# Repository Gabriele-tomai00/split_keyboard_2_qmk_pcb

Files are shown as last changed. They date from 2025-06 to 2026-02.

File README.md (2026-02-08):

# SPLIT KEYBOARD (my second version)

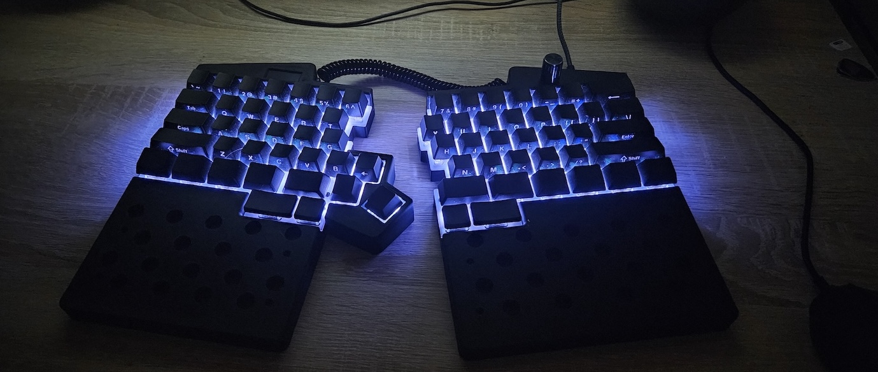
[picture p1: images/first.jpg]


<!-- ## ⚠️ Report In Progress ⚠️ -->
This project details the design and construction of my first custom split keyboard. The build features a custom PCB, hand-soldered components, and a 3D-printed case, all powered by the Raspberry Pi Pico and QMK firmware.

**Key Features:**
- **Microcontroller**: Raspberry Pi Pico (RP2040)
- **Firmware**: QMK with Vial GUI support
- **Switches**: Hot-swappable MX switches
- **Displays**: OLED status screens
- **Input**: Rotary encoders
- **Interconnect**: RJ11 cabling for safe hot-plugging

The layout is a traditional row-staggered design (non-ortholinear) with ergonomic enhancements:
- **Inner Macro Keys**: 3 extra keys on the inner side of the right half.
- **Thumb Cluster**: 2 low-profile keys under each spacebar, primarily used as layer modifiers.

*Acknowledgments: Special thanks to the QMK and Vial communities, and the authors of the Sofle Pico keyboard, whose work provided invaluable inspiration and knowledge.*

## Repository Structure
- `/3d_images`: 3D design files (STL) created with Autodesk Fusion 360
- `/images`: Photographic documentation of the keyboard assembly and final build.
- `/kicad`: Electrical schematics and PCB layout designs developed in KiCad, ready for fabrication.
- `/vial-qmk`: Source code for the QMK-based firmware with Vial GUI support.
- `/vial_config.vil`: Vial configuration file (you can upload this file to Vial to configure the keyboard).
- `/perimeter_right.dxf` and `/perimeter_left.dxf`: DXF files for the right and left half PCB perimeter (used to cut the PCB).

## Components List
- Custom PCBs (Left & Right)
- 2x Raspberry Pi Pico
- 1N4148 Diodes
- Kailh Hot-swap Sockets
- SK6812MINI-E SMD LEDs
- EC11 Rotary Encoders
- 0.91" I2C OLED Displays
- RJ11 Jacks (6P6C or similar)
- Brass Standoffs (M2)

## Features & Implementation

### Layout & Ergonomics
The keyboard deviates slightly from a standard 60% ANSI layout to accommodate split ergonomics. It combines standard MX switches with low-profile switches for the thumb cluster to reduce strain. The extra macro keys on the left half provide quick access to custom functions.

### Software (QMK & Vial)
The keyboard runs on QMK firmware and is fully compatible with Vial. This allows for real-time configuration via a graphical interface without re-flashing. Users can program:
- **Layers**: Toggle between different keymaps (e.g., QWERTY, navigation, numpad).
- **Macros**: Automate complex key sequences.
- **Tap Dance**: Assign different actions to a key based on how many times it is tapped.

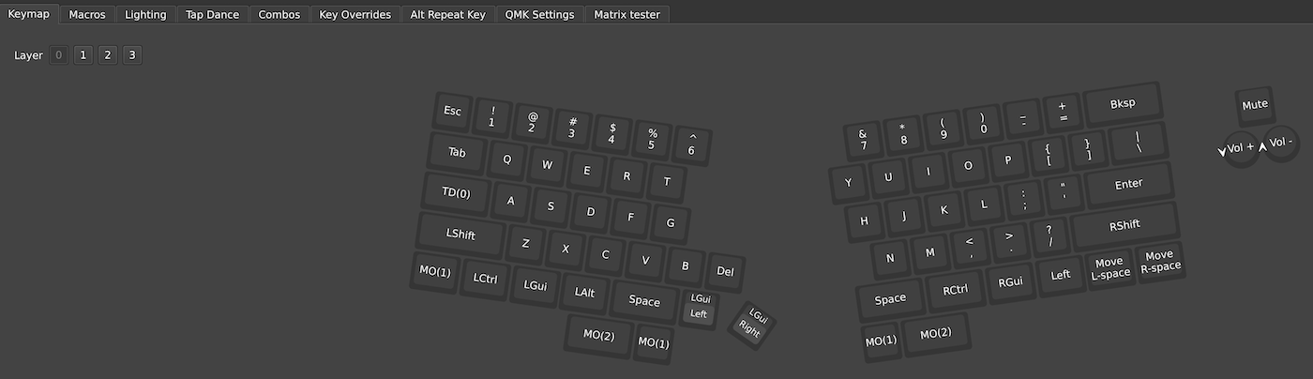
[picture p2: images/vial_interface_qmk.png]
Vial Interface


### Rotary Encoders (EC11)
The keyboard utilizes EC11 rotary encoders. In the QMK ecosystem, encoders provide a fluid input method distinct from binary key presses. They are ideal for continuous values like volume control, page scrolling, or history navigation.

### OLED Displays
Each half is equipped with an OLED display connected via the I2C protocol.

OLED Display

### RGB Backlighting (SK6812MINI-E)
The PCB features per-key RGB backlighting using SK6812MINI-E LEDs.
- **Technology**: These addressable "reverse-mount" LEDs sit within PCB cutouts, shining upwards through the switch housing.
- **Effects**: Powered by QMK's RGB Matrix system, the keyboard supports vast lighting animations, reactive typing effects, and layer-specific color coding (e.g., turning the keyboard red when on the "Function" layer).

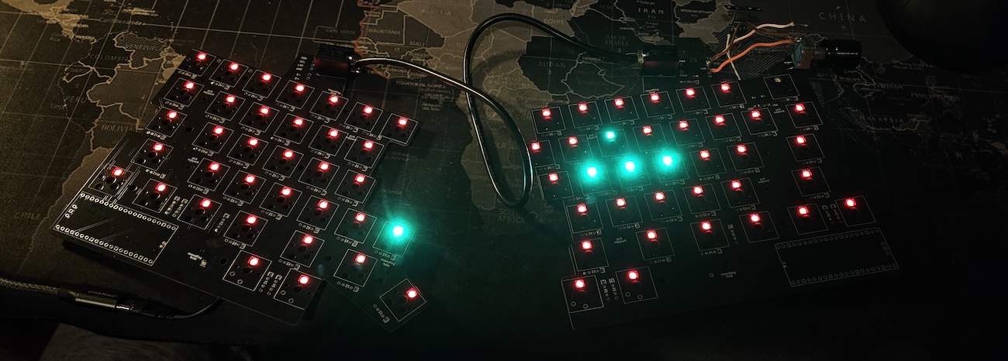
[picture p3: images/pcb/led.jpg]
PCB LED

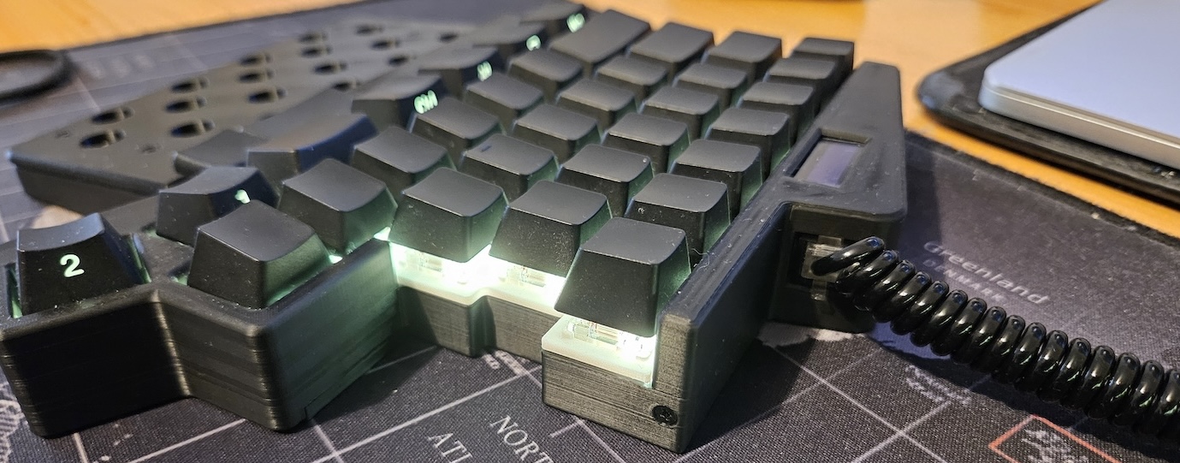
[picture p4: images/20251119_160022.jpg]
Backlighting


## Hardware Details

### Microcontroller: Raspberry Pi Pico (RP2040)
I selected the Raspberry Pi Pico for this build due to its generous GPIO count compared to the Pro Micro. With 26 usable GPIO pins, the RP2040 handles the matrix, encoders, OLEDs, and RGB data lines directly, simplifying the PCB design.

### Split Connection: UART via RJ11
Communication between the two halves uses Full Duplex UART over an RJ11 cable (inspired by the Ultimate Hacking Keyboard).
- **Why RJ11?**: Unlike the common TRRS (Aux) cables used in many split keyboards, RJ11 connectors do not short pins momentarily during insertion or removal. This design choice eliminates the risk of shorting VCC to GND while the keyboard is powered.

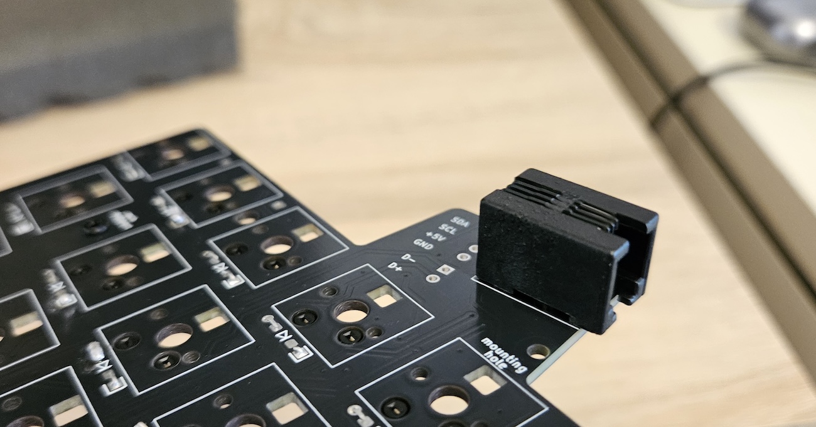
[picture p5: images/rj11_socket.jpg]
RJ11 Socket


I constructed a custom cable using 4-pin RJ11 connectors (6P4C) attached to a 4-core wire. It is crucial to ensure the connectors support at least 4 pins, avoiding the common 2-pin variants typically used for telephone lines in Italy.

### USB Type-C Connectivity
Each keyboard half features a dedicated USB Type-C port for computer connectivity. I chose this standard for its versatility and widespread adoption. The port is distinct from the inter-half connection to prevent accidental mismatches. Either half can be connected to the host computer.
I referenced the Raspberry Pi Pico datasheet to correctly wire the external USB-C breakout board to the microcontroller, ensuring the Pico detects the external connection as its primary USB interface.

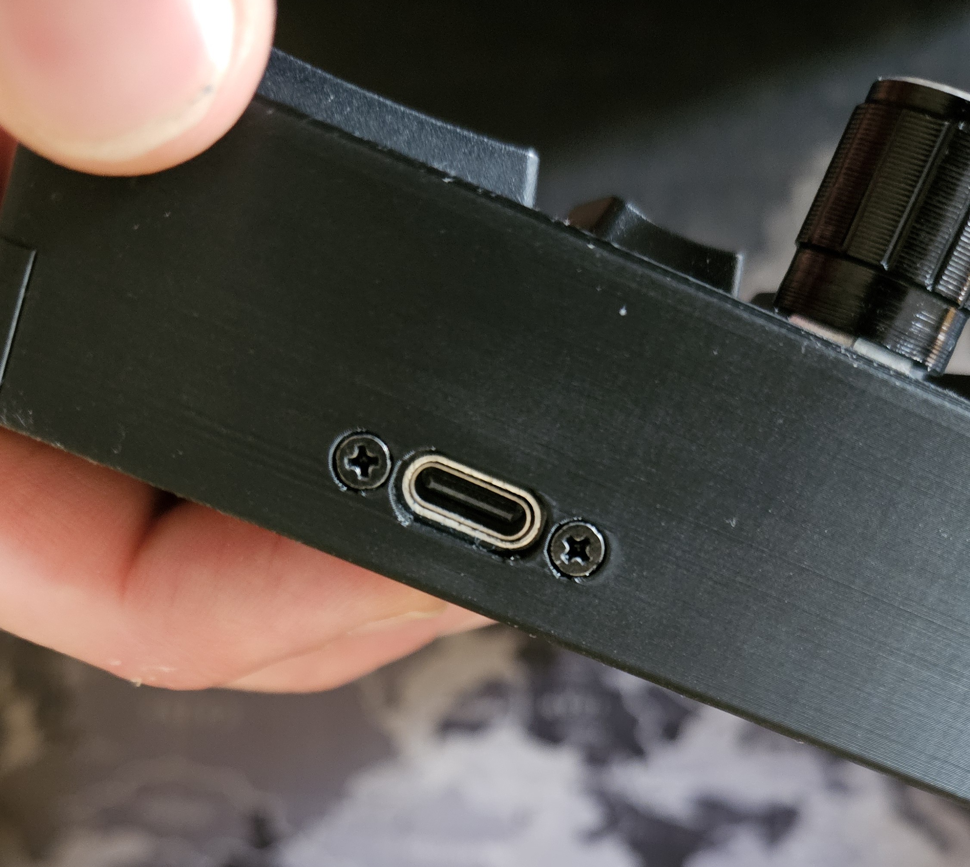
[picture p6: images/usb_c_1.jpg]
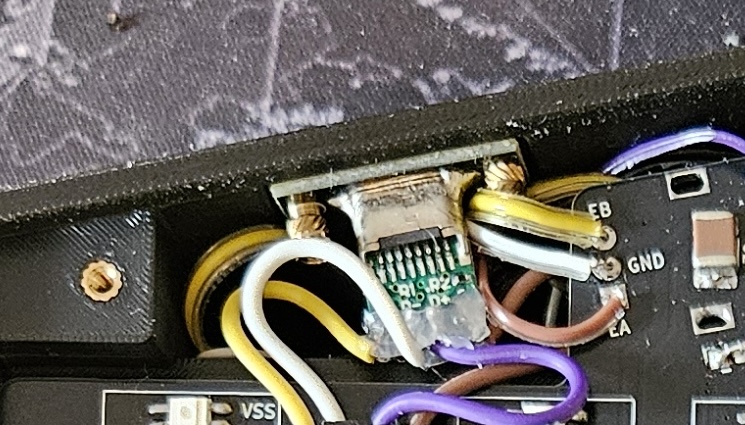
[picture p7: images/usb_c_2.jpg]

### Key Matrix Wiring
QMK supports a key matrix configuration where each key is identified by a unique row-column combination, with diodes preventing ghosting (unwanted column activation).
The PCB and QMK firmware are configured as follows:
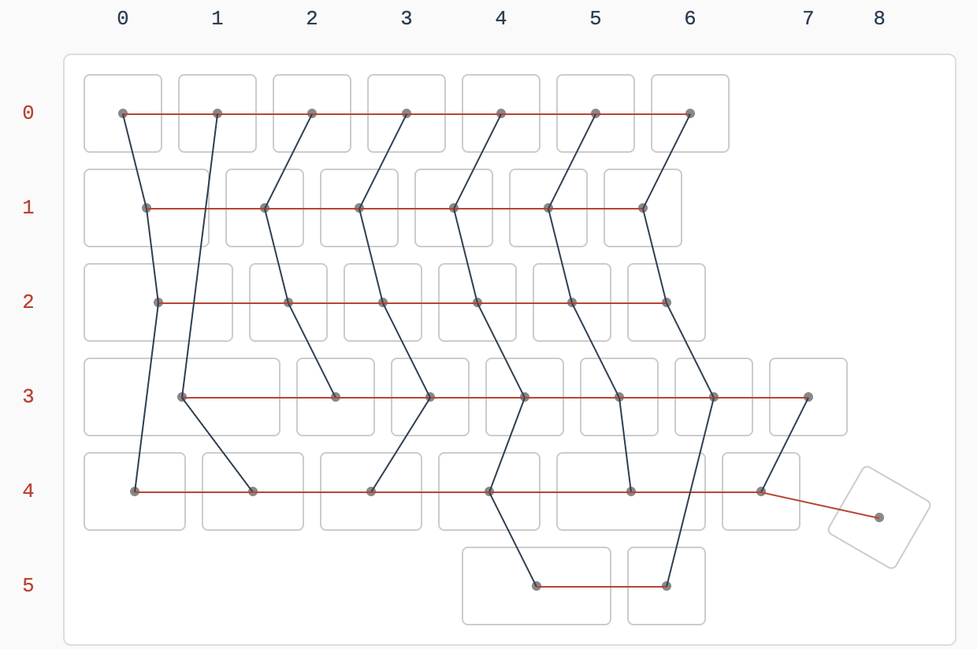
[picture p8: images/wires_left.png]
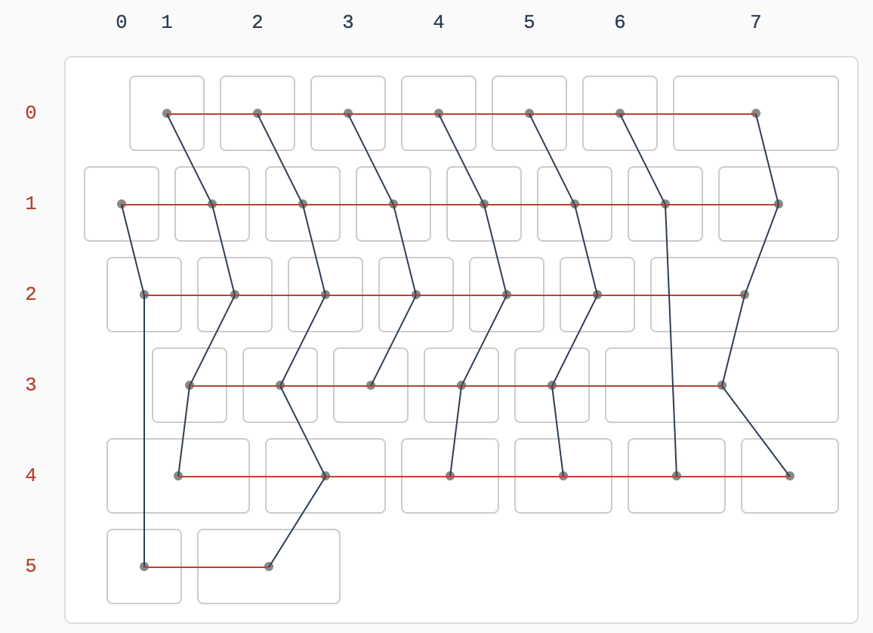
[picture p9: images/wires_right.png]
 

## 3D-Printed Case Design
I designed with Autodesk Fusion 360 and printed a custom enclosure using PLA. The chassis is modular, divided into multiple parts to:
- Allow for easy replacement of individual components without re-printing the entire case.
- Reduce print time per part (avoiding >20h single prints).

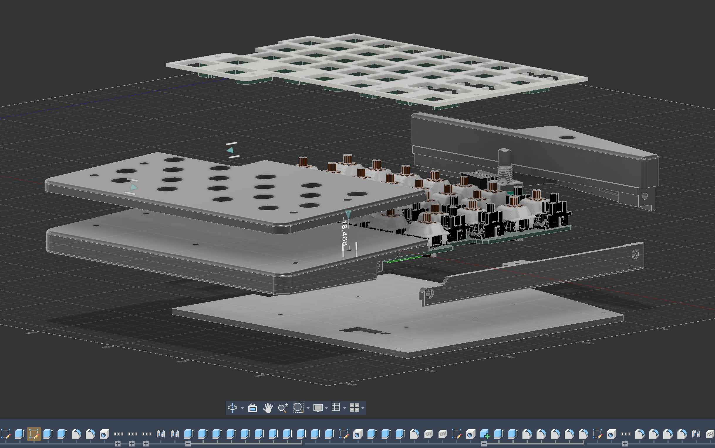
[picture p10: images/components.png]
Components


### 3D Printing Process
The enclosure components were manufactured using a Bambu Lab P1P 3D printer. While the design is compatible with standard printing profiles, a 0.2mm nozzle was utilized to achieve superior surface finish and precise detail resolution.
PLA (Polylactic Acid) was selected as the filament material due to its optimal balance of cost-effectiveness, printability, and mechanical durability suitable for this application.

### Assembly
The case uses threaded brass inserts (M2) for a robust and aesthetically pleasing assembly.
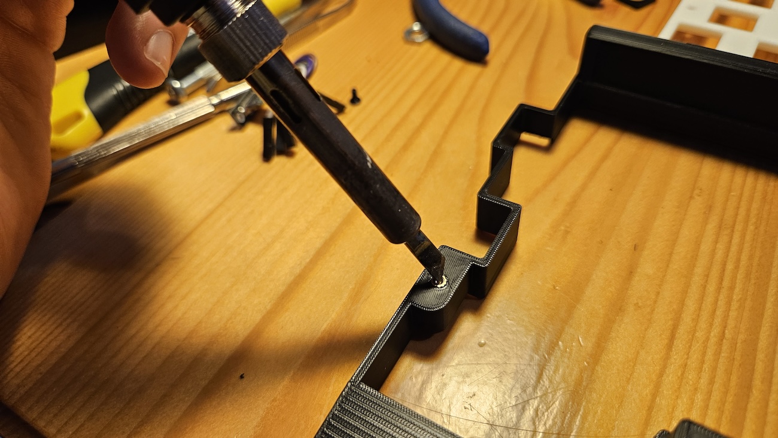
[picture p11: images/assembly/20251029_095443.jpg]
Case Assembly

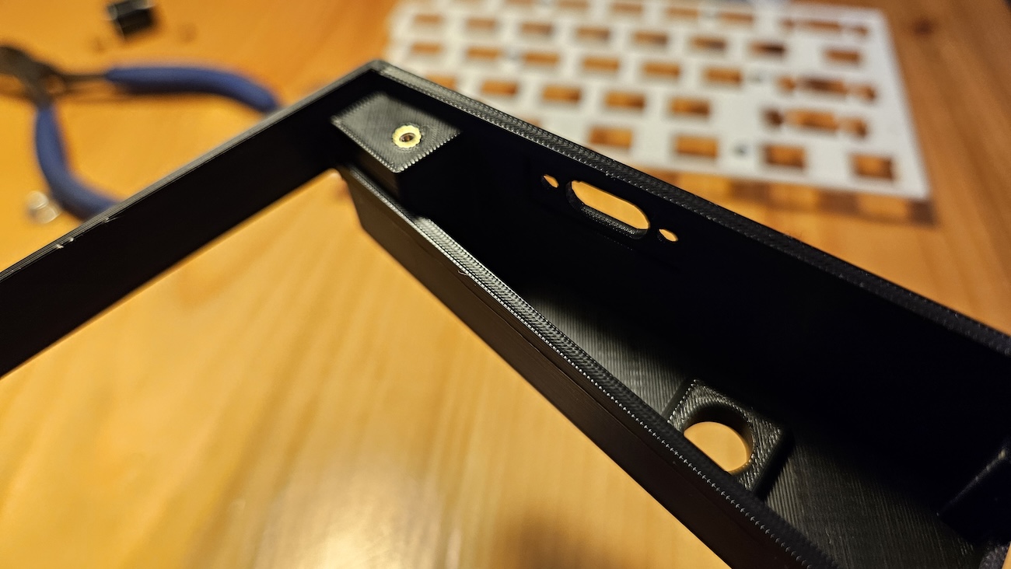
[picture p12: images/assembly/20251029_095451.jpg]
Case Assembly

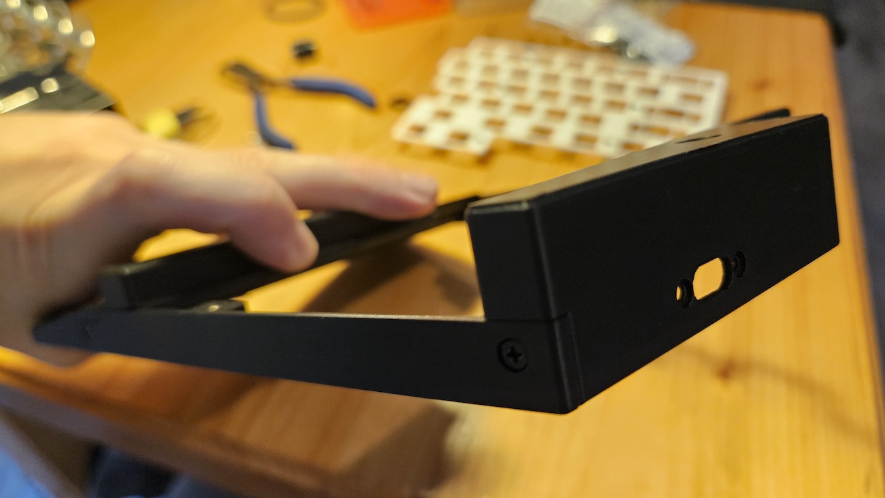
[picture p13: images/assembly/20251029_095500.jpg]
Case Assembly


## Component Assembly & Soldering
All PCB components were hand-soldered, which included:
- **Raspberry Pi Pico**: Soldering all GPIO pins plus the two small test pads required for the external USB data lines.
- **Passive Components**: 2 capacitors per PCB.
- **Connectors**: External USB-C breakout (4 pins) and RJ11 jacks (4 pins).
- **Peripherals**: Rotary encoders (5 pins) and OLED display headers (4 pins).

For the matrix:
- **Diodes**: 1N4148 diodes for each key (2 points).
- **Sockets**: Kailh hot-swap sockets (2 points) - switches are not soldered directly.
- **LEDs**: SK6812MINI-E SMD LEDs (4 points per key).

A significant challenge was soldering the small voltage level shifter required for correct LED data signaling. As this was my first experience with soldering—especially with such small SMD components—the results are functional but reflect the learning curve involved.

## Flashing Instructions
1. Set up the **vial-qmk** environment by cloning the repository: [https://github.com/vial-kb/vial-qmk](https://github.com/vial-kb/vial-qmk).
2. Copy the `qmk-vial/new_split_keyboard_gabriele` directory from this project into the `vial-qmk/keyboards/` directory.
3. Flash the firmware using the following commands:

```bash
# Flash Left Side
qmk flash -kb new_split_keyboard_gabriele -km vial -bl uf2-split-left

# Flash Right Side
qmk flash -kb new_split_keyboard_gabriele -km vial -bl uf2-split-right
```

## Conclusions
Additional photographic documentation is available in the `/images` directory.

## References
- [QMK Firmware](https://qmk.fm/)
- [Raspberry Pi Pico Datasheet](https://datasheets.raspberrypi.com/pico/pico-datasheet.pdf)
- [Sofle Pico Split Keyboard](https://www.soflepico.com)
- [Ultimate Hacking Keyboard - blog](https://uhk.io/blog)
- [VIAL](https://blog.4dcu.be/diy/2023/12/03/pi-pico-usb-c.html)
- [Simple USB Type-C Upgrade for the Raspberry Pi Pico](https://blog.4dcu.be/diy/2023/12/03/pi-pico-usb-c.html)

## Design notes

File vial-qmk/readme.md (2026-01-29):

## Steps
1. Move this git repository to keyboards repository of vial-qmk and rename it to "split_keyboard_gabriele"  
2. use the command (qmk compile -kb "name of the keyboard folder" -km "name of the keyboard layout that is vial if you want to use with vial): 
    `qmk clean && qmk compile -kb new_split_keyboard_gabriele -km vial` or directly `qmk clean && qmk flash -kb new_split_keyboard_gabriele -km vial` (you need a Rasberry Pi Pico linked and in flash mode)
3. It's comulasary use usb connection for the left hand. If you want to link the right hand, you need to change the option #define MASTER_LEFT in config.h

`clear && qmk flash -kb new_split_keyboard_gabriele -km vial` 

`clear && qmk clean && qmk flash -kb new_split_keyboard_gabriele -km vial -bl uf2-split-left` 
`clear && qmk clean && qmk flash -kb new_split_keyboard_gabriele -km vial -bl uf2-split-right`

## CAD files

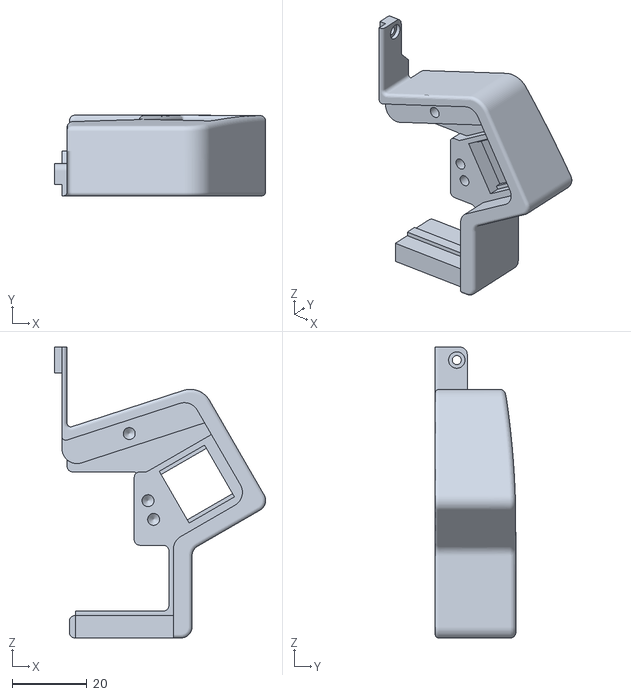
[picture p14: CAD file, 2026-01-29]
3d_models/left_keyboard_part/3-key_keypad.stl
56.5 x 21.6 x 77.9

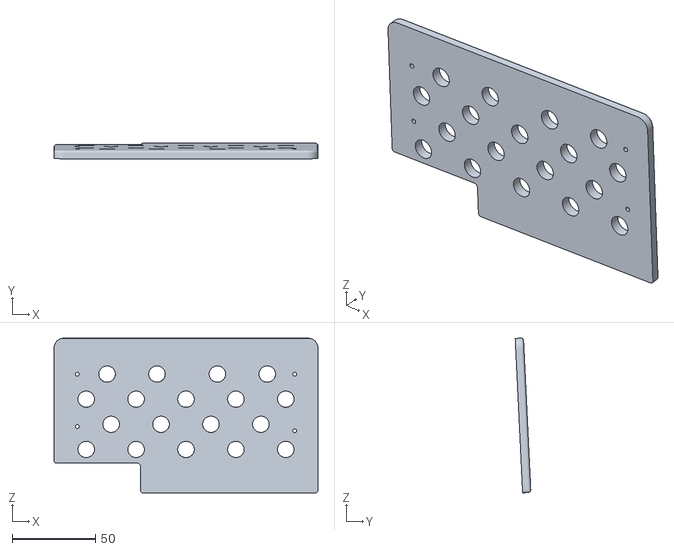
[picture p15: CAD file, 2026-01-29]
3d_models/right_keyboard_part/palm_rest_right.stl
158.7 x 9.38 x 93.1

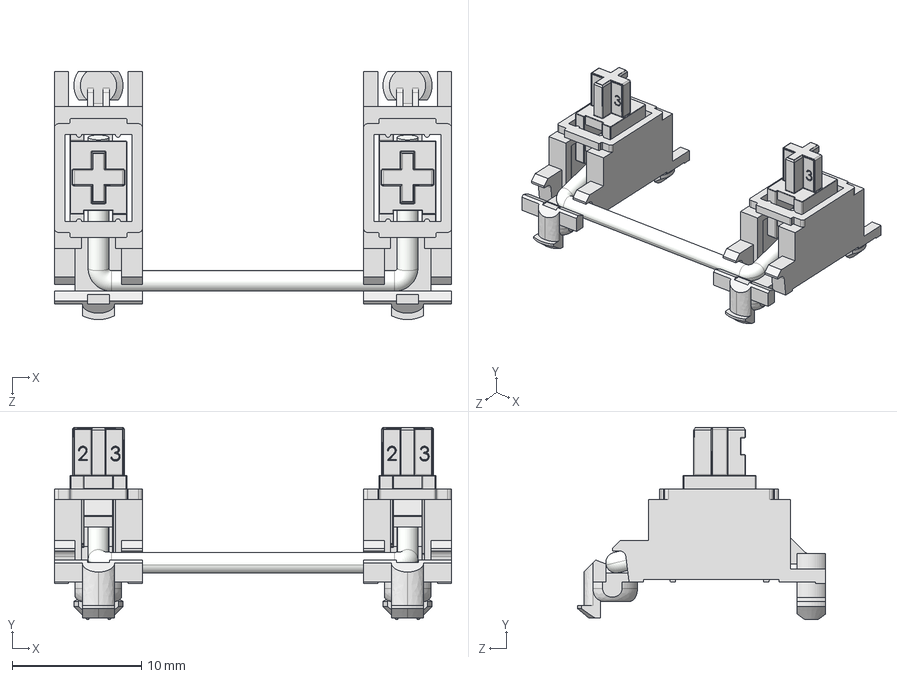
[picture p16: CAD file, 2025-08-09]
kicad/3d_models/Stabilizer.STEP
30.7 x 14.9 x 19.2 mm
mx Stabilizer base 16828 x 2
mx Stabilizer key 16828 x 2
metal stick 16828

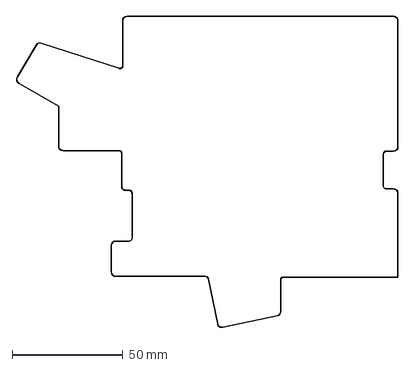
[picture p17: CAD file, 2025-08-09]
kicad/pcb_keyboard_left/perimetro_left.dxf
172.6 x 140.8 mm

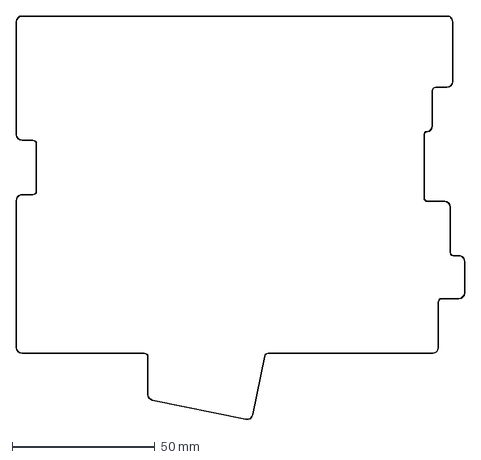
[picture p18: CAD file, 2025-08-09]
kicad/pcb_keyboard_right/perimetro_right.dxf
156.8 x 141.3 mm

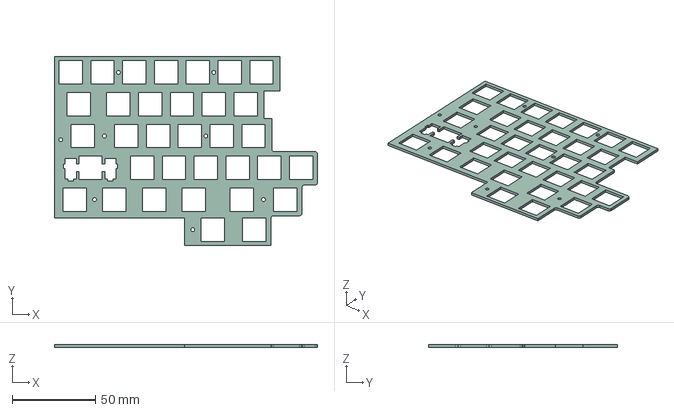
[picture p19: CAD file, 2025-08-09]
kicad/plate/plate_left/plate_left.step
157.6 x 113.2 x 1.60 mm

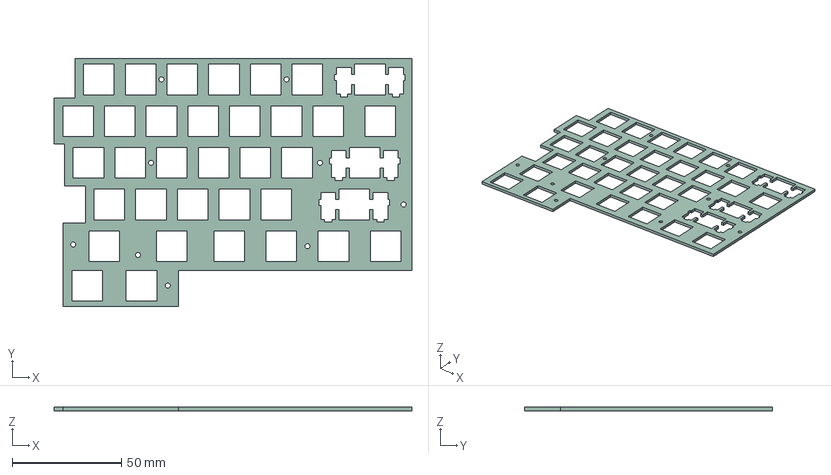
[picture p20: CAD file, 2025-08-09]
kicad/plate/plate_right/plate_right.step
163.6 x 113.2 x 1.60 mm

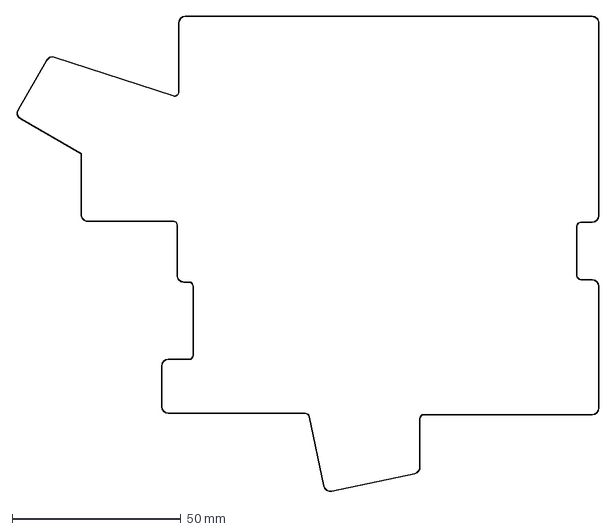
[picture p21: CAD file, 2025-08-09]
perimeter_left.dxf
172.6 x 140.8 mm

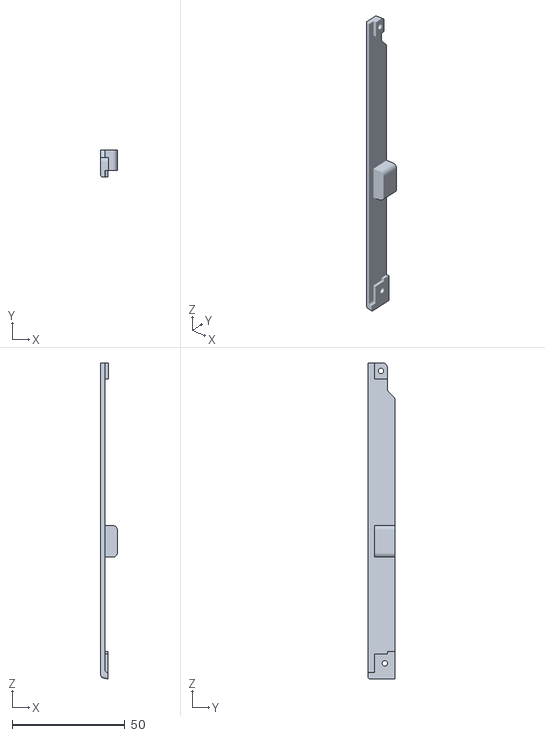
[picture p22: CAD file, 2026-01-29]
3d_models/left_keyboard_part/external_wall_left.stl
7.44 x 12.0 x 139.9

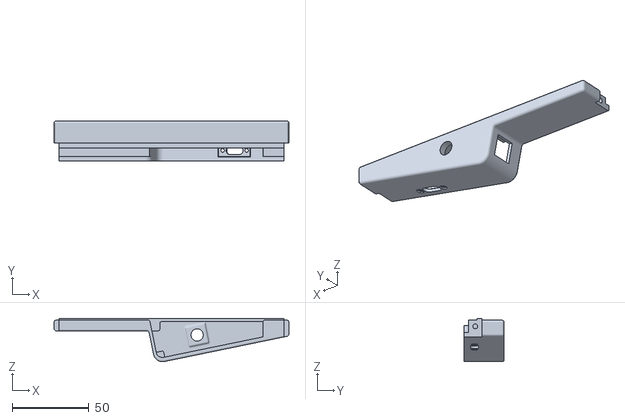
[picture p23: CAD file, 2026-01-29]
3d_models/right_keyboard_part/upper_right.stl
153.4 x 26.4 x 28.4

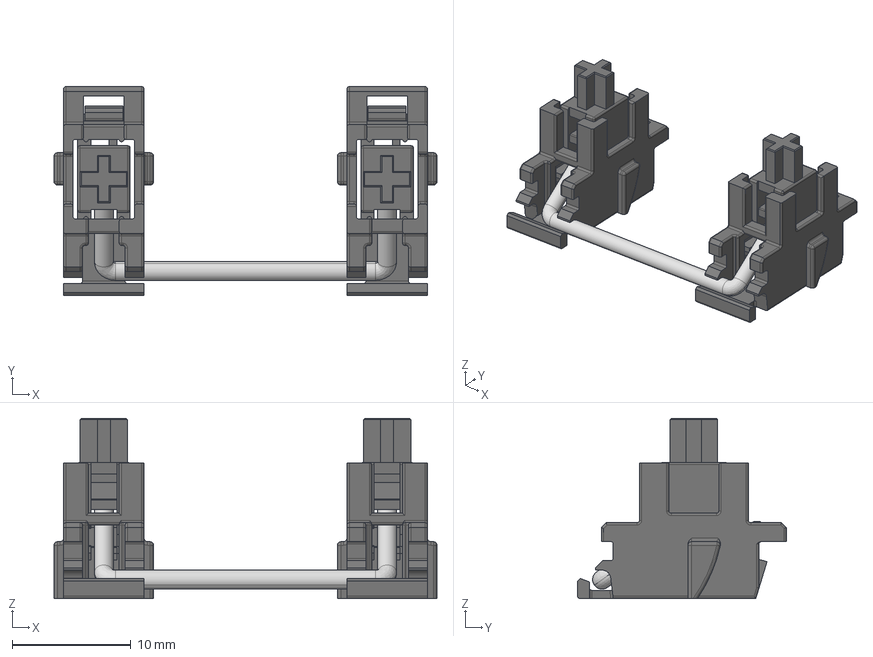
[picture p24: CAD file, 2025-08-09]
kicad/3d_models/stabilizzatore.step
32.3 x 17.6 x 15.2 mm
STABIL_DOWN_MX x 2
STABIL_MX x 2
MX_METAL

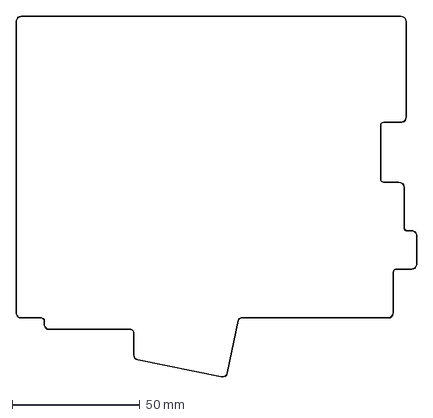
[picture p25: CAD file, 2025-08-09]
perimeter_right.dxf
156.8 x 141.3 mm

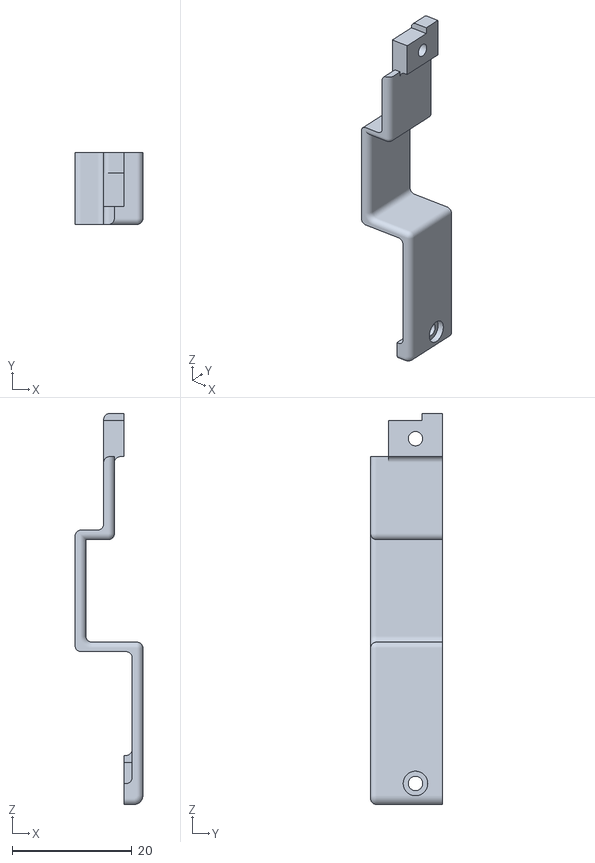
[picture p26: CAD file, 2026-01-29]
3d_models/left_keyboard_part/internal_wall_left.stl
11.3 x 12.0 x 65.2

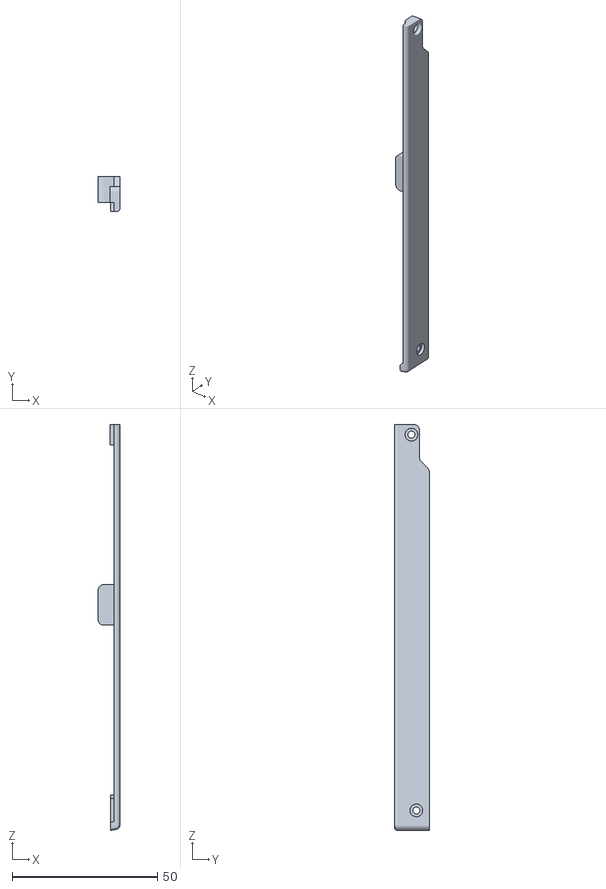
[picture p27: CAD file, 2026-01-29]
3d_models/right_keyboard_part/external_wall_right.stl
7.57 x 12.0 x 139.9

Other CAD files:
kicad/3d_models/Raspberry_Pi_Pico_micro_usb.step
3d_models/left_keyboard_part/cover_left.stl
3d_models/right_keyboard_part/cover_right.stl
kicad/3d_models/vite_punta_torx.step
3d_models/left_keyboard_part/keyboard_left.stl
3d_models/left_keyboard_part/palm_rest_left.stl
3d_models/left_keyboard_part/upper_left.stl
3d_models/right_keyboard_part/internal_wall_right.stl
3d_models/right_keyboard_part/keyboard_right.stl
kicad/3d_models/OLED_128x32.step
kicad/3d_models/RJ11_CONNECTOR.step
kicad/3d_models/Raspberry_Pi_Pico.step
kicad/3d_models/cilindro_3mm.step
kicad/3d_models/cilindro_4mm.step
kicad/3d_models/cilindro_9mm.step
kicad/3d_models/encoder_ALPS.step
kicad/3d_models/vite_M2_4mm.step
kicad/plate/plate_left/plate_left.dxf
kicad/plate/plate_right/plate_right.dxf

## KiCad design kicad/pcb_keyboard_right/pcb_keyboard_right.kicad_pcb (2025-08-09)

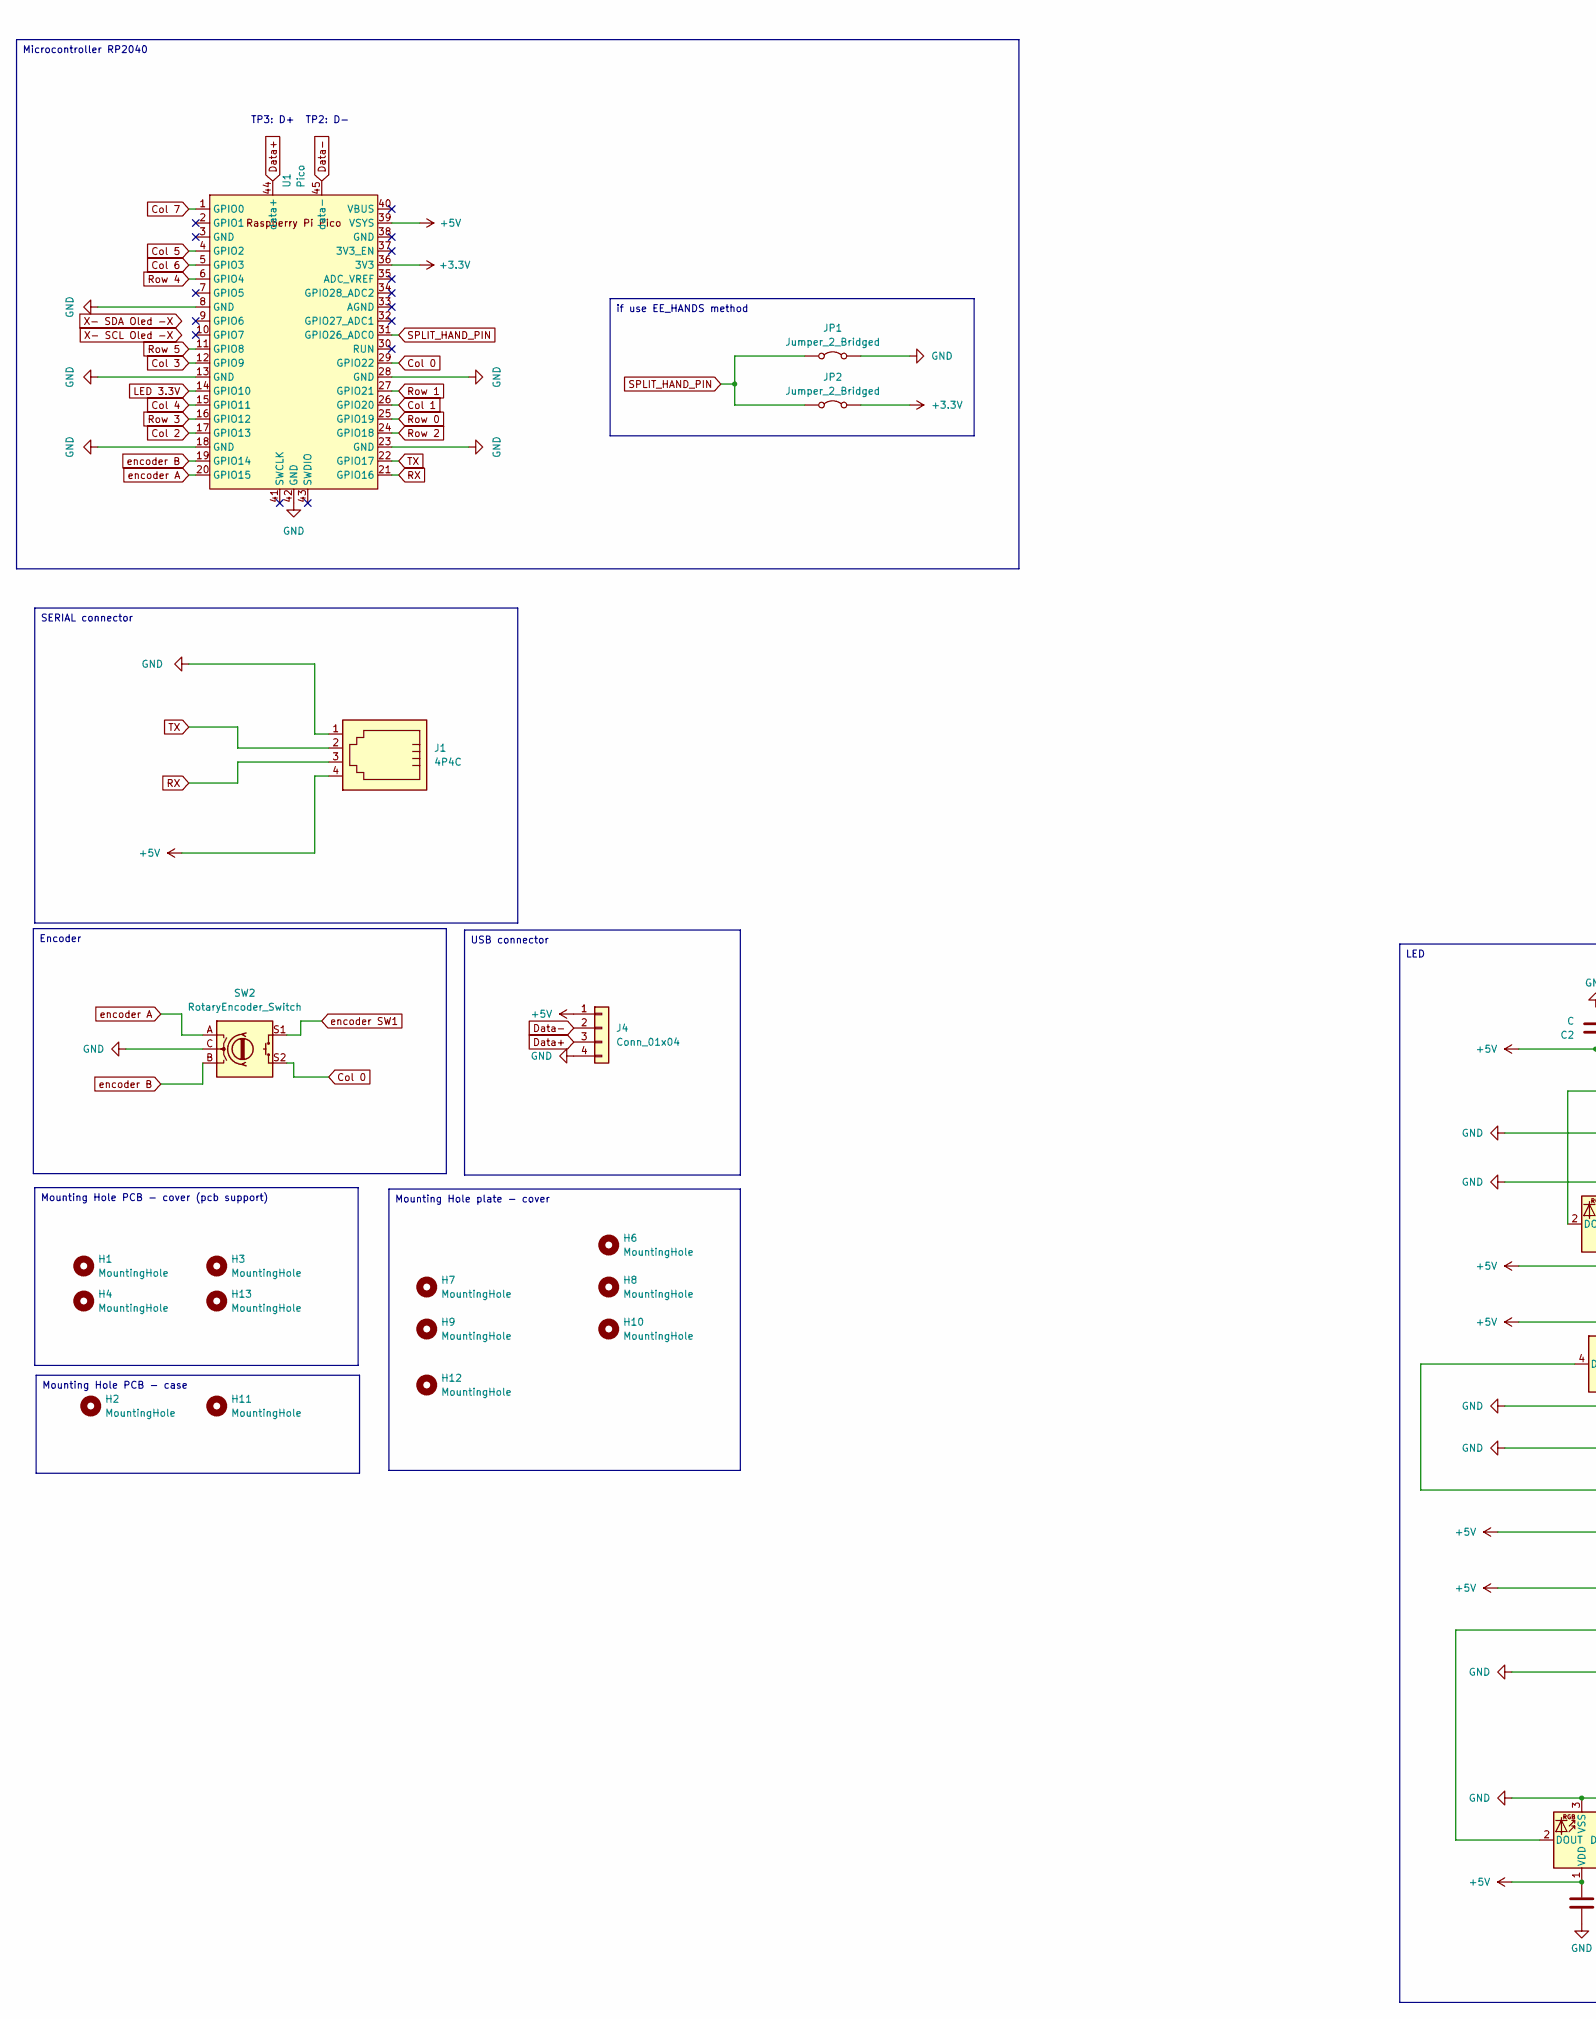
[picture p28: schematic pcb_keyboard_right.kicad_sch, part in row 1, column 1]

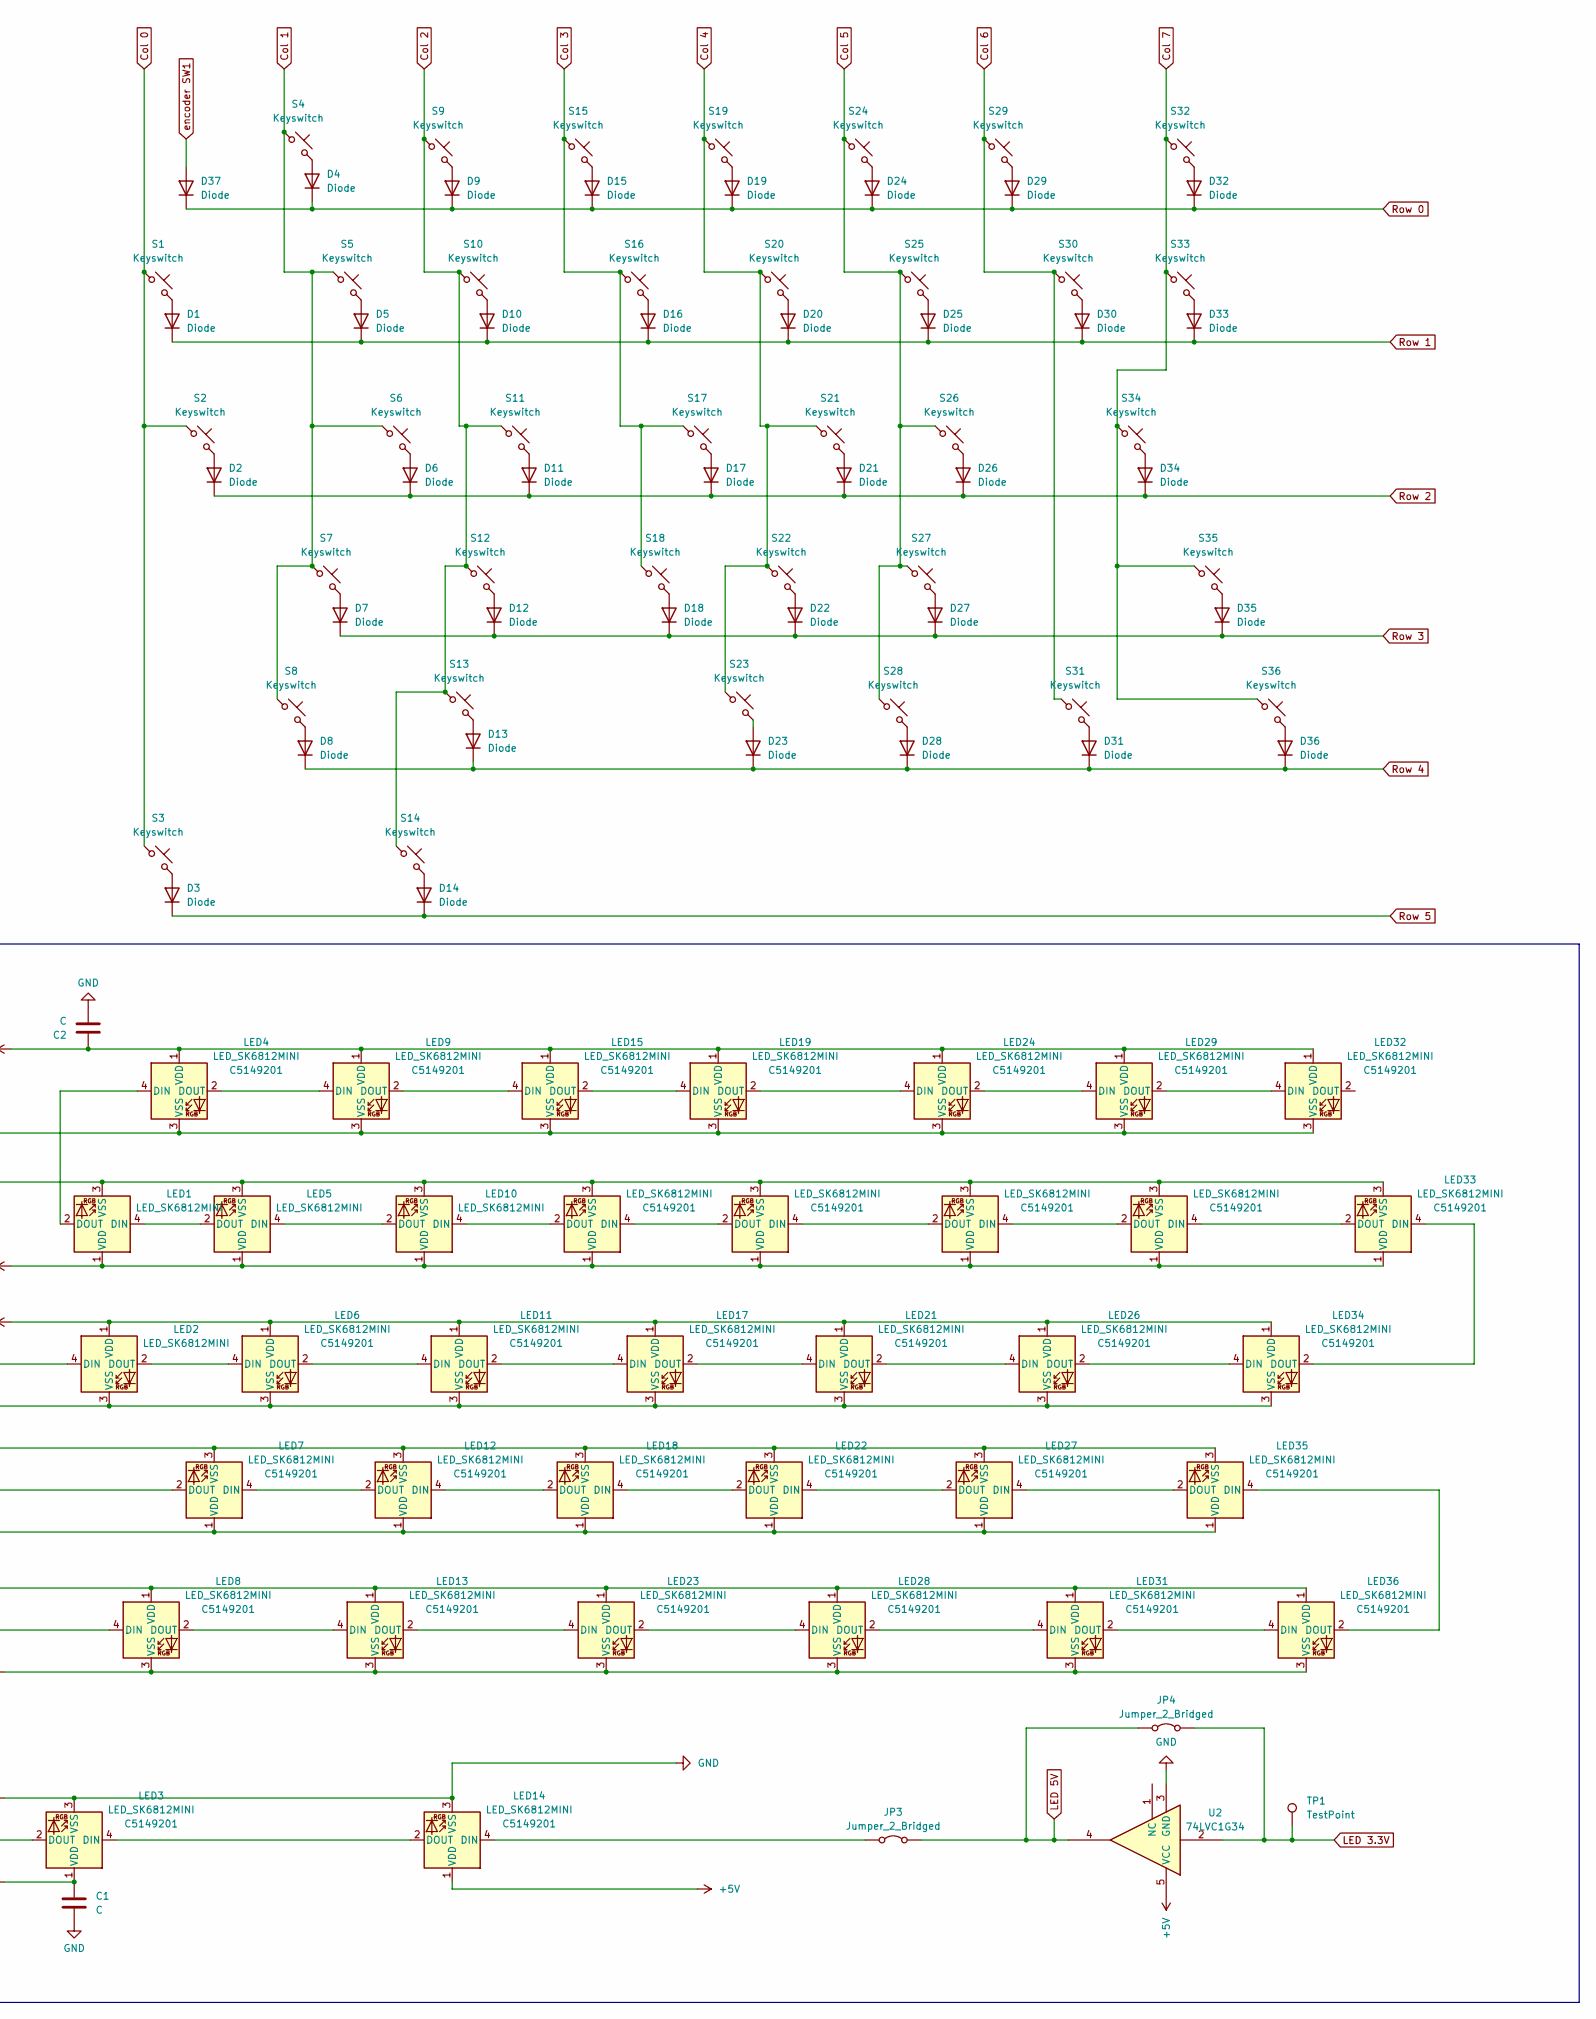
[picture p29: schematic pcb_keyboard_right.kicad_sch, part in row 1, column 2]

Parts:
C1, C2: C; C_1812_4532Metric_Pad1.57x3.40mm_HandSolder
D1, D2, D3, D4, D5, D6, D7, D8, D9, D10, D11, D12, D13, D14, D15, D16, D17, D18, D19, D20, D21, D22, D23, D24, D25, D26, D27, D28, D29, D30, D31, D32, D33, D34, D35, D36, D37: Diode; D_SOD-123_DO-35_Hybrid_DoubleSided_diode
H1, H3, H4, H13: MountingHole; PCB_support_2.2mm_M2
H2, H11: MountingHole; MountingPCB_2.2mm_M2
H6, H7, H8, H9, H10, H12: MountingHole; MountingHole_3.2mm_M3
J1: 4P4C; RJ12_Amphenol_54601-x06_Horizontal
J4: Conn_01x04; PinHeader_1x04_P2.54mm_Horizontal
JP1, JP2, JP3, JP4: Jumper_2_Bridged; SolderJumper-2_P1.3mm_Bridged2Bar_Pad1.0x1.5mm
LED1, LED2, LED3, LED4, LED5, LED6, LED7, LED8, LED9, LED10, LED11, LED12, LED13, LED14, LED15, LED16, LED17, LED18, LED19, LED20, LED21, LED22, LED23, LED24, LED25, LED26, LED27, LED28, LED29, LED30, LED31, LED32, LED33, LED34, LED35, LED36: LED_SK6812MINI; LCSC C5149201
S1, S2, S4, S5, S6, S7, S9, S10, S11, S12, S15, S16, S17, S18, S19, S20, S21, S22, S24, S25, S26, S27, S29, S30: Keyswitch; Hotswap_MX_1.00u
S3: Keyswitch; Choc_V1_1.00u
S8: Keyswitch; Hotswap_MX_1.75u
S13, S33: Keyswitch; Hotswap_MX_1.50u
S14: Keyswitch; Choc_V1_1.75u
S23, S28, S31, S36: Keyswitch; Hotswap_MX_1.25u
S32: Keyswitch; Hotswap_MX_2.00u
S34: Keyswitch; Hotswap_MX_2.25u
S35: Keyswitch; Hotswap_MX_2.75u
SW2: RotaryEncoder_Switch; Encoder_EC11_MX
TP1: TestPoint; PinHeader_1x01_P2.54mm_Vertical
U1: Pico; Raspberry_Pi_Pico_with_usb_rings
U2: 74LVC1G34; SOT-353_SC-70-5_Handsoldering

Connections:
+3.3V: JP2.2 (B), U1.36 (3V3)
+5V: C1.1, C2.1, J1.4, J4.1, LED1.1 (VDD), LED2.1 (VDD), LED3.1 (VDD), LED4.1 (VDD), LED5.1 (VDD), LED6.1 (VDD), LED7.1 (VDD), LED8.1 (VDD), LED9.1 (VDD), LED10.1 (VDD), LED11.1 (VDD), LED12.1 (VDD), LED13.1 (VDD), LED14.1 (VDD), LED15.1 (VDD), LED16.1 (VDD), LED17.1 (VDD), LED18.1 (VDD), LED19.1 (VDD), LED20.1 (VDD), LED21.1 (VDD), LED22.1 (VDD), LED23.1 (VDD), LED24.1 (VDD), LED25.1 (VDD), LED26.1 (VDD), LED27.1 (VDD), LED28.1 (VDD), LED29.1 (VDD), LED30.1 (VDD), LED31.1 (VDD), LED32.1 (VDD), LED33.1 (VDD), LED34.1 (VDD), LED35.1 (VDD), LED36.1 (VDD), U1.39 (VSYS), U2.5 (VCC)
Col 0: S1.1, S2.1, S3.1, SW2.S2, U1.29 (GPIO22)
Col 1: S4.1, S5.1, S6.1, S7.1, S8.1, U1.26 (GPIO20)
Col 2: S9.1, S10.1, S11.1, S12.1, S13.1, S14.1, U1.17 (GPIO13)
Col 3: S15.1, S16.1, S17.1, S18.1, U1.12 (GPIO9)
Col 4: S19.1, S20.1, S21.1, S22.1, S23.1, U1.15 (GPIO11)
Col 5: S24.1, S25.1, S26.1, S27.1, S28.1, U1.4 (GPIO2)
Col 6: S29.1, S30.1, S31.1, U1.5 (GPIO3)
Col 7: S32.1, S33.1, S34.1, S35.1, S36.1, U1.1 (GPIO0)
Data+: J4.3, U1.44 (data+)
Data-: J4.2, U1.45 (data-)
GND: C1.2, C2.2, J1.1, J4.4, JP1.2 (B), LED1.3 (VSS), LED2.3 (VSS), LED3.3 (VSS), LED4.3 (VSS), LED5.3 (VSS), LED6.3 (VSS), LED7.3 (VSS), LED8.3 (VSS), LED9.3 (VSS), LED10.3 (VSS), LED11.3 (VSS), LED12.3 (VSS), LED13.3 (VSS), LED14.3 (VSS), LED15.3 (VSS), LED16.3 (VSS), LED17.3 (VSS), LED18.3 (VSS), LED19.3 (VSS), LED20.3 (VSS), LED21.3 (VSS), LED22.3 (VSS), LED23.3 (VSS), LED24.3 (VSS), LED25.3 (VSS), LED26.3 (VSS), LED27.3 (VSS), LED28.3 (VSS), LED29.3 (VSS), LED30.3 (VSS), LED31.3 (VSS), LED32.3 (VSS), LED33.3 (VSS), LED34.3 (VSS), LED35.3 (VSS), LED36.3 (VSS), SW2.C, U1.8 (GND), U1.13 (GND), U1.18 (GND), U1.23 (GND), U1.28 (GND), U1.42 (GND), U2.3 (GND)
LED 3.3V: JP4.2 (B), TP1.1, U1.14 (GPIO10), U2.2
LED 5V: JP3.2 (B), JP4.1 (A), U2.4
unnamed: D1.2 (A), S1.2
unnamed: D2.2 (A), S2.2
unnamed: D3.2 (A), S3.2
unnamed: D4.2 (A), S4.2
unnamed: D5.2 (A), S5.2
unnamed: D6.2 (A), S6.2
unnamed: D7.2 (A), S7.2
unnamed: D8.2 (A), S8.2
unnamed: D9.2 (A), S9.2
unnamed: D10.2 (A), S10.2
unnamed: D11.2 (A), S11.2
unnamed: D12.2 (A), S12.2
unnamed: D13.2 (A), S13.2
unnamed: D14.2 (A), S14.2
unnamed: D15.2 (A), S15.2
unnamed: D16.2 (A), S16.2
unnamed: D17.2 (A), S17.2
unnamed: D18.2 (A), S18.2
unnamed: D19.2 (A), S19.2
unnamed: D20.2 (A), S20.2
unnamed: D21.2 (A), S21.2
unnamed: D22.2 (A), S22.2
unnamed: D23.2 (A), S23.2
unnamed: D24.2 (A), S24.2
unnamed: D25.2 (A), S25.2
unnamed: D26.2 (A), S26.2
unnamed: D27.2 (A), S27.2
unnamed: D28.2 (A), S28.2
unnamed: D29.2 (A), S29.2
unnamed: D30.2 (A), S30.2
unnamed: D31.2 (A), S31.2
unnamed: D32.2 (A), S32.2
unnamed: D33.2 (A), S33.2
unnamed: D34.2 (A), S34.2
unnamed: D35.2 (A), S35.2
unnamed: D36.2 (A), S36.2
unnamed: JP3.1 (A), LED14.4 (DIN)
unnamed: LED1.4 (DIN), LED5.2 (DOUT)
unnamed: LED1.2 (DOUT), LED4.4 (DIN)
unnamed: LED2.4 (DIN), LED7.2 (DOUT)
unnamed: LED2.2 (DOUT), LED6.4 (DIN)
unnamed: LED3.2 (DOUT), LED8.4 (DIN)
unnamed: LED4.2 (DOUT), LED9.4 (DIN)
unnamed: LED10.4 (DIN), LED16.2 (DOUT)
unnamed: LED5.4 (DIN), LED10.2 (DOUT)
unnamed: LED6.2 (DOUT), LED11.4 (DIN)
unnamed: LED11.2 (DOUT), LED17.4 (DIN)
unnamed: LED12.4 (DIN), LED18.2 (DOUT)
unnamed: LED7.4 (DIN), LED12.2 (DOUT)
unnamed: LED8.2 (DOUT), LED13.4 (DIN)
unnamed: LED13.2 (DOUT), LED23.4 (DIN)
unnamed: LED3.4 (DIN), LED14.2 (DOUT)
unnamed: LED9.2 (DOUT), LED15.4 (DIN)
unnamed: LED15.2 (DOUT), LED19.4 (DIN)
unnamed: LED16.4 (DIN), LED20.2 (DOUT)
unnamed: LED17.2 (DOUT), LED21.4 (DIN)
unnamed: LED18.4 (DIN), LED22.2 (DOUT)
unnamed: LED19.2 (DOUT), LED24.4 (DIN)
unnamed: LED20.4 (DIN), LED25.2 (DOUT)
unnamed: LED21.2 (DOUT), LED26.4 (DIN)
unnamed: LED22.4 (DIN), LED27.2 (DOUT)
unnamed: LED23.2 (DOUT), LED28.4 (DIN)
unnamed: LED24.2 (DOUT), LED29.4 (DIN)
unnamed: LED25.4 (DIN), LED30.2 (DOUT)
unnamed: LED26.2 (DOUT), LED34.4 (DIN)
unnamed: LED27.4 (DIN), LED35.2 (DOUT)
unnamed: LED28.2 (DOUT), LED31.4 (DIN)
unnamed: LED29.2 (DOUT), LED32.4 (DIN)
unnamed: LED30.4 (DIN), LED33.2 (DOUT)
unnamed: LED31.2 (DOUT), LED36.4 (DIN)
unnamed: LED33.4 (DIN), LED34.2 (DOUT)
unnamed: LED35.4 (DIN), LED36.2 (DOUT)
RX: J1.3, U1.21 (GPIO16)
Row 0: D4.1 (K), D9.1 (K), D15.1 (K), D19.1 (K), D24.1 (K), D29.1 (K), D32.1 (K), D37.1 (K), U1.25 (GPIO19)
Row 1: D1.1 (K), D5.1 (K), D10.1 (K), D16.1 (K), D20.1 (K), D25.1 (K), D30.1 (K), D33.1 (K), U1.27 (GPIO21)
Row 2: D2.1 (K), D6.1 (K), D11.1 (K), D17.1 (K), D21.1 (K), D26.1 (K), D34.1 (K), U1.24 (GPIO18)
Row 3: D7.1 (K), D12.1 (K), D18.1 (K), D22.1 (K), D27.1 (K), D35.1 (K), U1.16 (GPIO12)
Row 4: D8.1 (K), D13.1 (K), D23.1 (K), D28.1 (K), D31.1 (K), D36.1 (K), U1.6 (GPIO4)
Row 5: D3.1 (K), D14.1 (K), U1.11 (GPIO8)
SPLIT_HAND_PIN: JP1.1 (A), JP2.1 (A), U1.31 (GPIO26_ADC0)
TX: J1.2, U1.22 (GPIO17)
encoder A: SW2.A, U1.20 (GPIO15)
encoder B: SW2.B, U1.19 (GPIO14)
encoder SW1: D37.2 (A), SW2.S1

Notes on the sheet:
Microcontroller RP2040
Mounting Hole PCB - case
LED
USB connector
Mounting Hole PCB - cover (pcb support)
if use EE_HANDS method
Mounting Hole plate - cover
Encoder
SERIAL connector
TP2: D-
TP3: D+

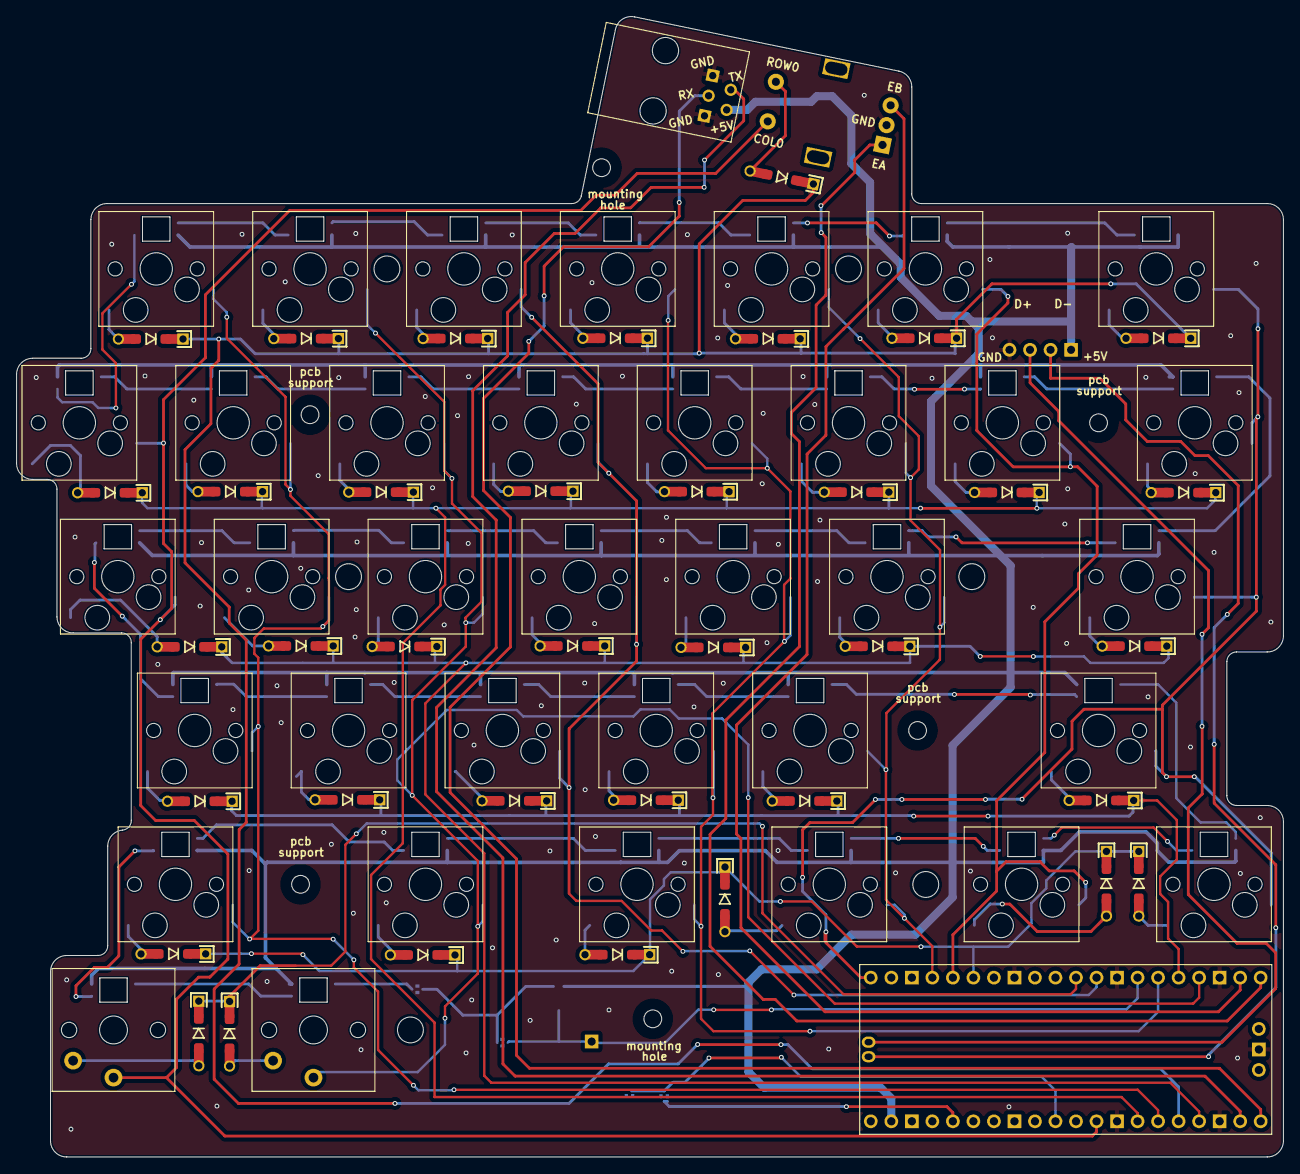
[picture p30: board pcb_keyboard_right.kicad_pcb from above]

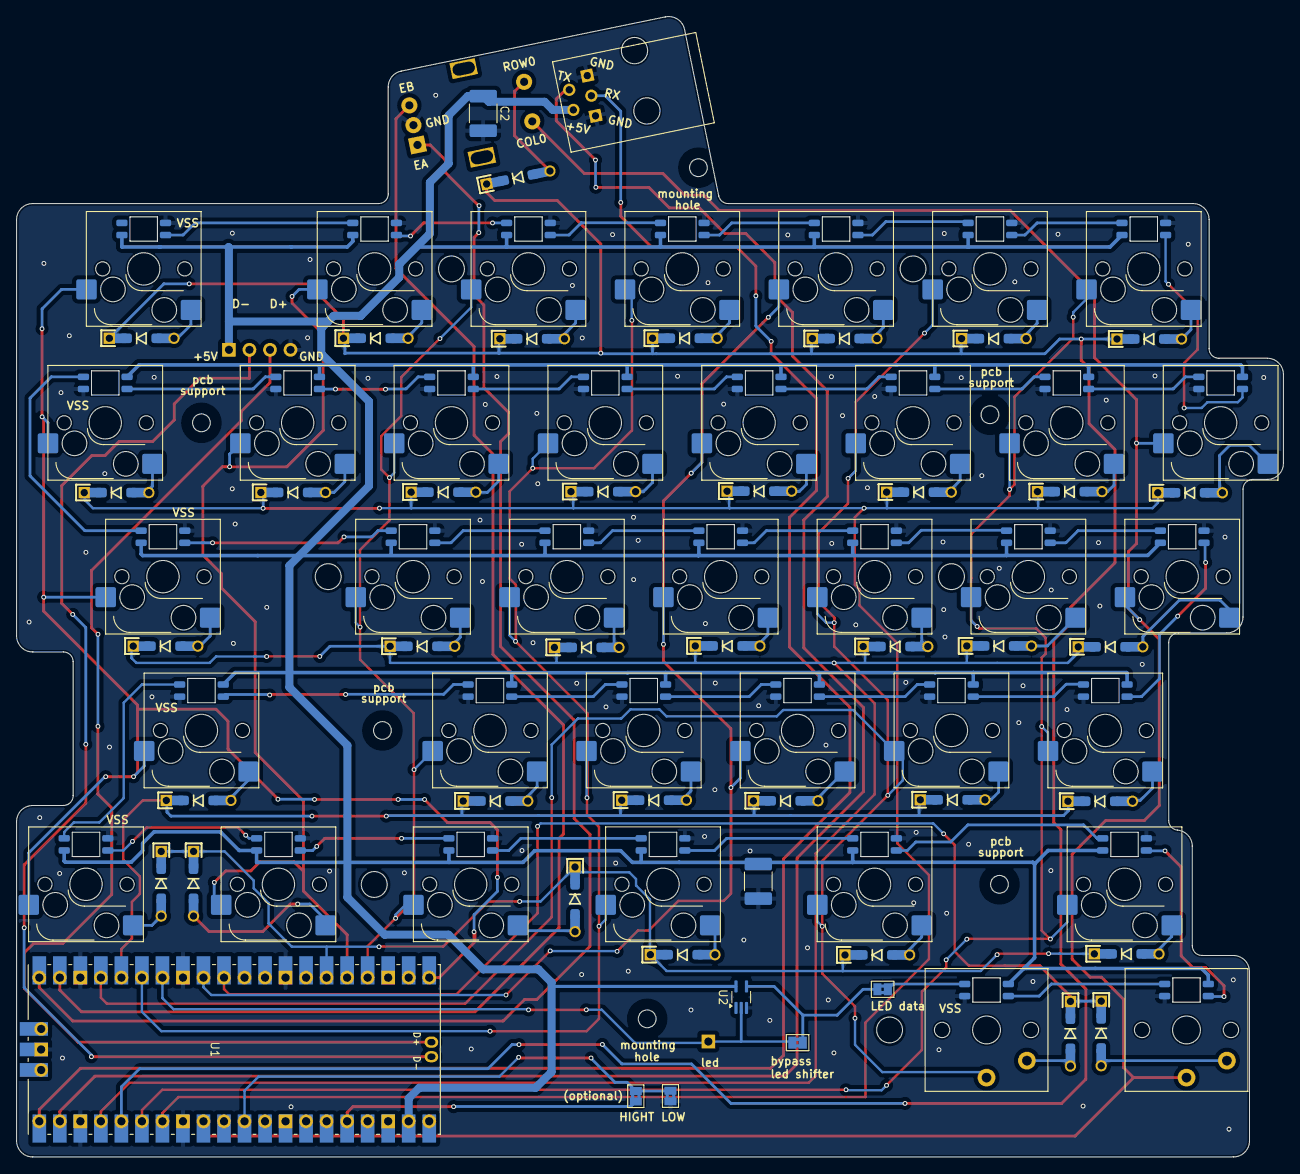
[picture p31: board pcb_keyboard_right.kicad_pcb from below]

Board: 2 copper layers, 156.8 x 141.1 mm, 133 parts (82 on the bottom side), 99 nets.

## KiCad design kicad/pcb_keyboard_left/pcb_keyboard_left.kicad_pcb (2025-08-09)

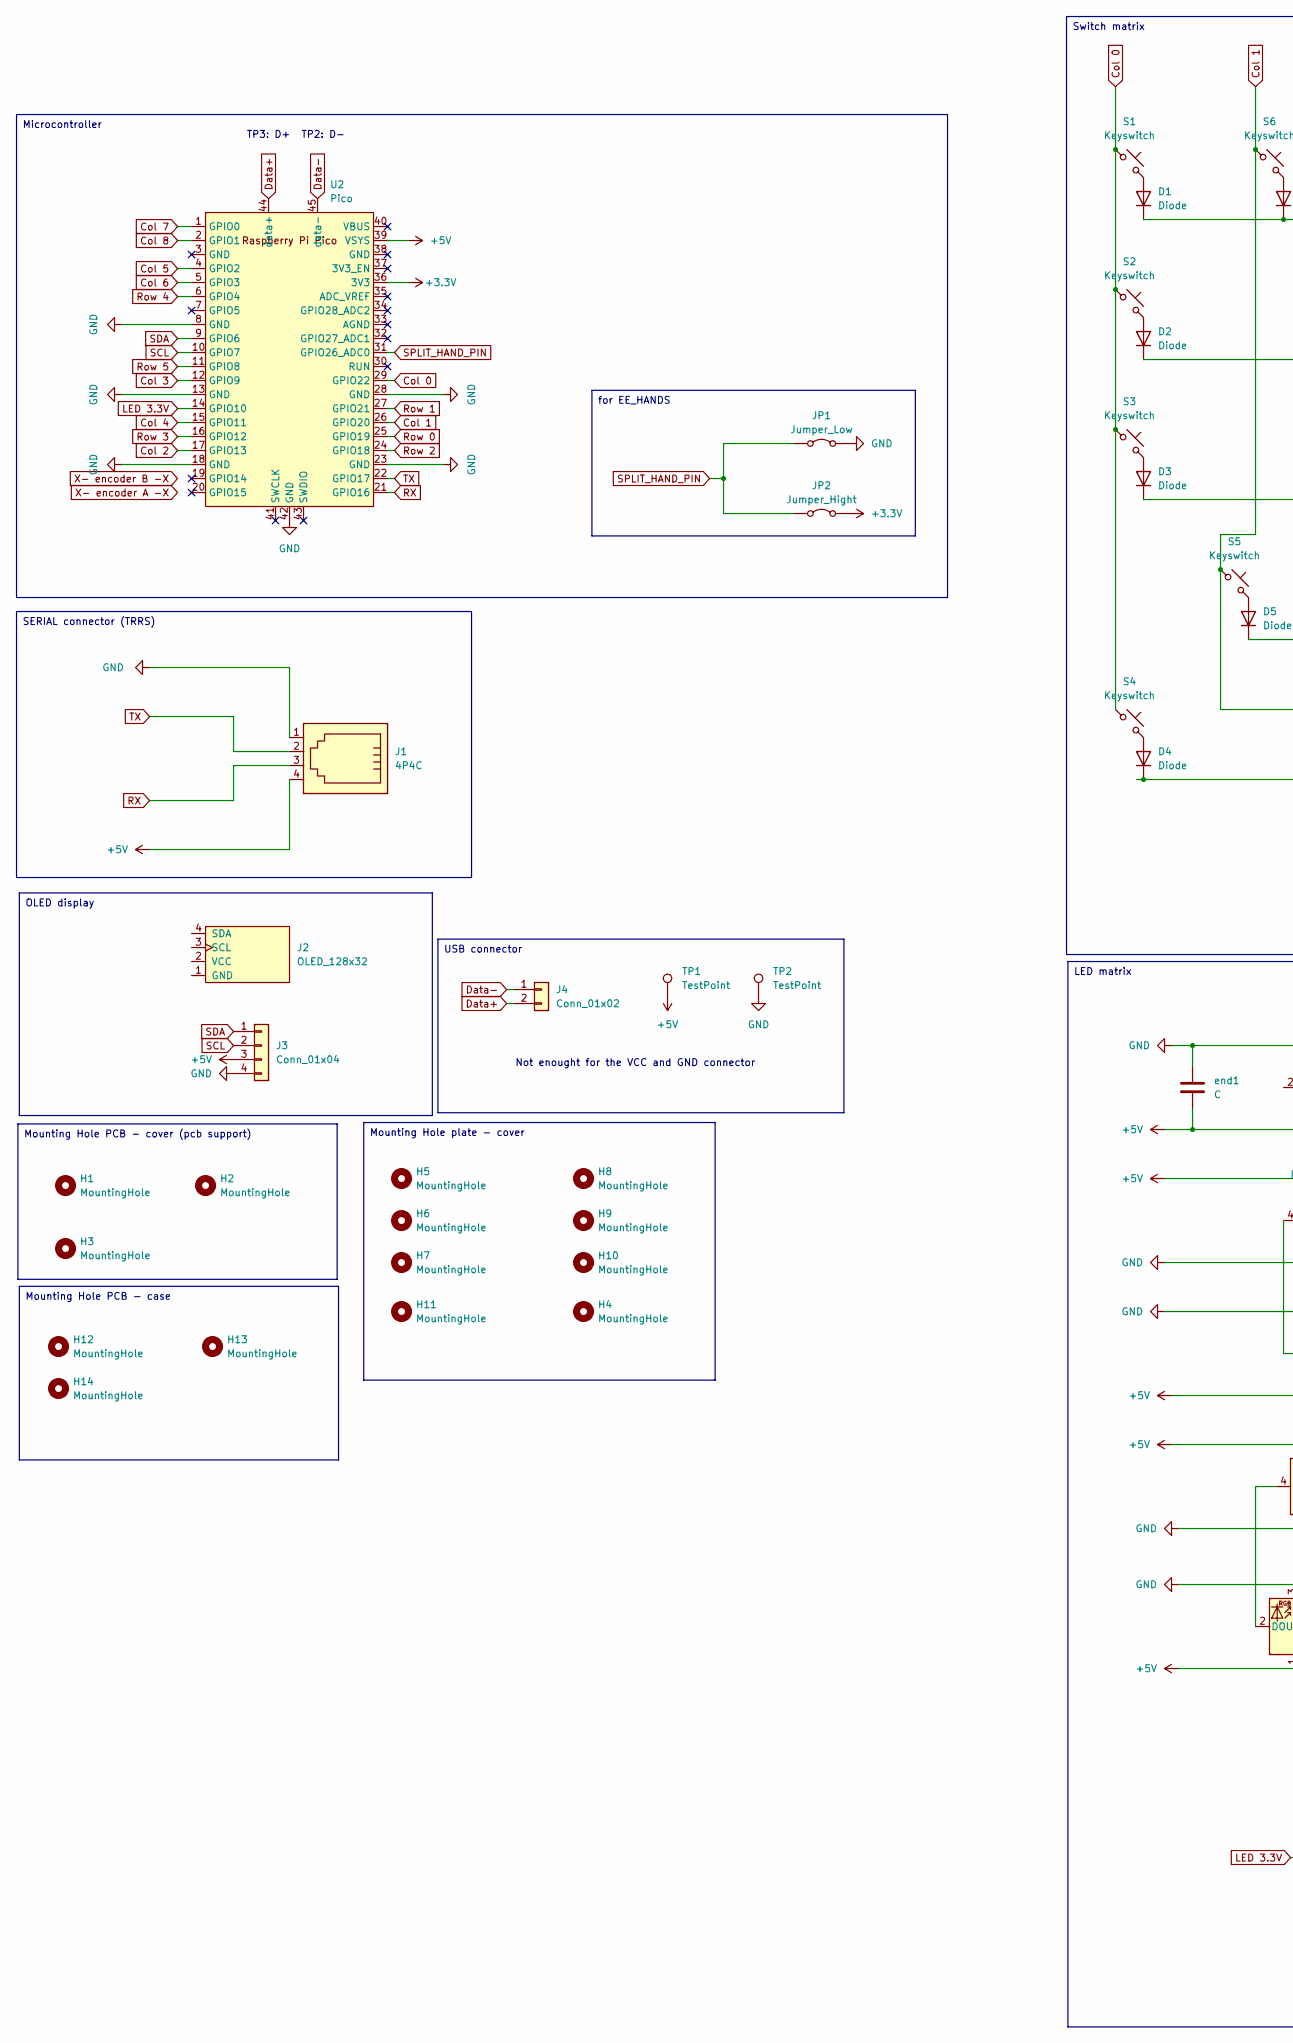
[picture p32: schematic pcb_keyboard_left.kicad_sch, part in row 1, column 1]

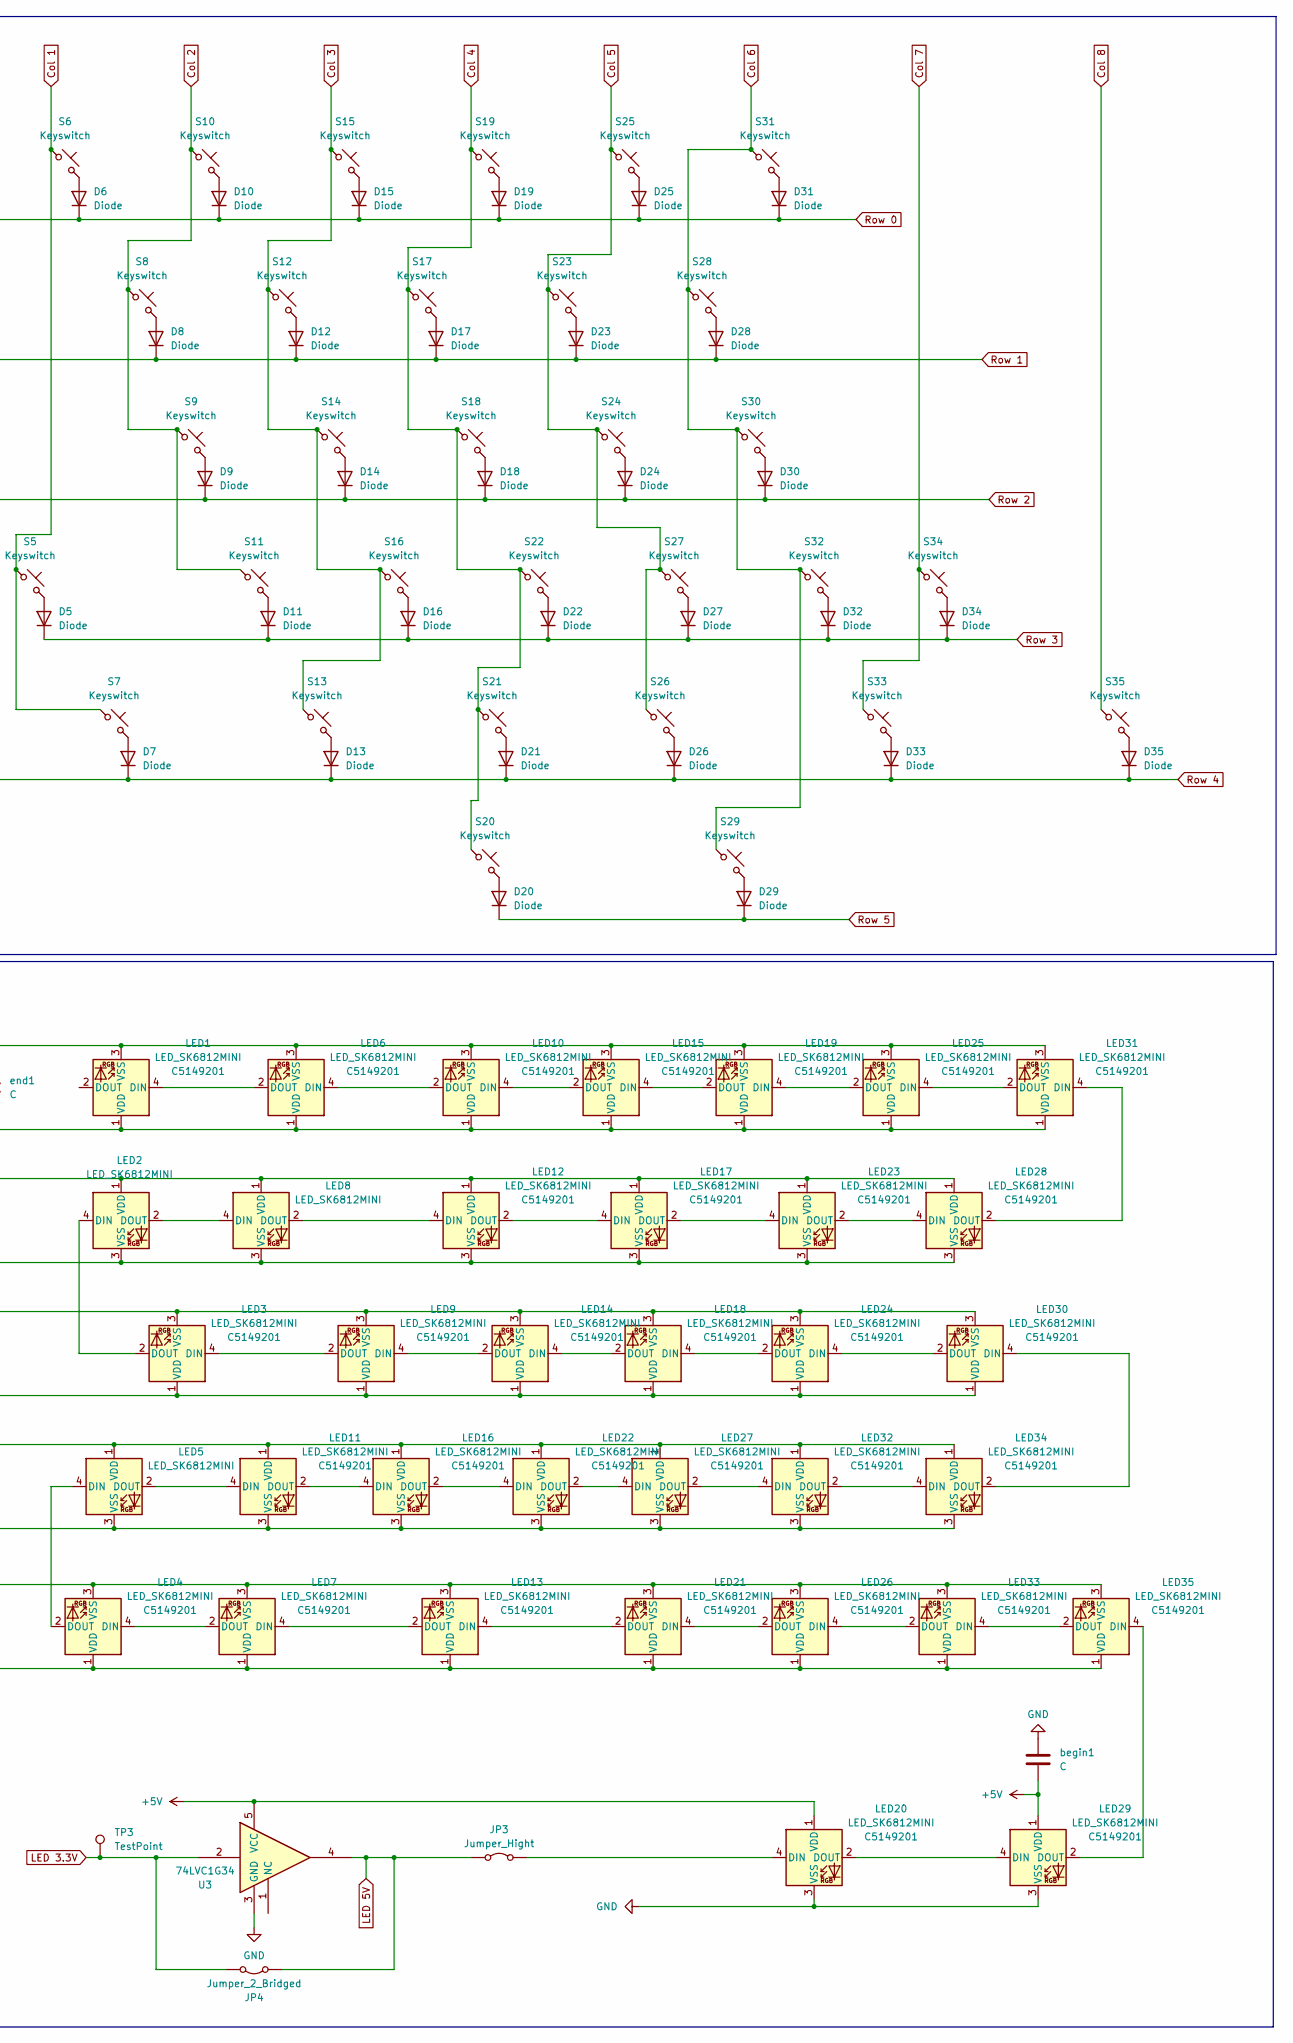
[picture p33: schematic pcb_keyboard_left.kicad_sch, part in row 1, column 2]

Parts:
D1, D2, D3, D4, D5, D6, D7, D8, D9, D10, D11, D12, D13, D14, D15, D16, D17, D18, D19, D20, D21, D22, D23, D24, D25, D26, D27, D28, D29, D30, D31, D32, D33, D34, D35: Diode; D_SOD-123_DO-35_Hybrid_DoubleSided_V2
H1, H2, H3: MountingHole; PCB_support_2.2mm_M2
H4, H5, H6, H7, H8, H9, H10, H11: MountingHole; MountingHole_3.2mm_M3
H12, H13, H14: MountingHole; MountingPCB_2.2mm_M2
J1: 4P4C; RJ12_Amphenol_54601-x06_Horizontal
J2: OLED_128x32
J3: Conn_01x04; PinHeader_1x04_P2.54mm_Horizontal
J4: Conn_01x02; PinHeader_1x02_P2.54mm_Horizontal
JP1: Jumper_Low; SolderJumper-2_P1.3mm_Bridged2Bar_Pad1.0x1.5mm
JP2, JP3: Jumper_Hight; SolderJumper-2_P1.3mm_Bridged2Bar_Pad1.0x1.5mm
JP4: Jumper_2_Bridged; SolderJumper-2_P1.3mm_Bridged2Bar_Pad1.0x1.5mm
LED1, LED2, LED3, LED4, LED5, LED6, LED7, LED8, LED9, LED10, LED11, LED12, LED13, LED14, LED15, LED16, LED17, LED18, LED19, LED20, LED21, LED22, LED23, LED24, LED25, LED26, LED27, LED28, LED29, LED30, LED31, LED32, LED33, LED34, LED35: LED_SK6812MINI; LCSC C5149201
S1, S6, S8, S9, S10, S11, S12, S14, S15, S16, S17, S18, S19, S22, S23, S24, S25, S27, S28, S30, S31, S32, S33, S34, S35: Keyswitch; Hotswap_MX_1.00u
S2: Keyswitch; Hotswap_MX_1.50u
S3, S26: Keyswitch; Hotswap_MX_1.75u
S4, S7, S13, S21: Keyswitch; Hotswap_MX_1.25u
S5: Keyswitch; Hotswap_MX_2.25u
S20: Keyswitch; Choc_V1_1.75u
S29: Keyswitch; Choc_V1_1.00u
TP1, TP2, TP3: TestPoint; PinHeader_1x01_P2.54mm_Vertical
U2: Pico; Raspberry_Pi_Pico_with_usb_rings
U3: 74LVC1G34; SOT-353_SC-70-5_Handsoldering
begin1: C; C_1812_4532Metric_Pad1.57x3.40mm_HandSolder
end1: C; C_1812_4532Metric_Pad1.57x3.40mm_HandSolder

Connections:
+3.3V: JP2.2 (B), U2.36 (3V3)
+5V: J1.4, J3.3, LED1.1 (VDD), LED2.1 (VDD), LED3.1 (VDD), LED4.1 (VDD), LED5.1 (VDD), LED6.1 (VDD), LED7.1 (VDD), LED8.1 (VDD), LED9.1 (VDD), LED10.1 (VDD), LED11.1 (VDD), LED12.1 (VDD), LED13.1 (VDD), LED14.1 (VDD), LED15.1 (VDD), LED16.1 (VDD), LED17.1 (VDD), LED18.1 (VDD), LED19.1 (VDD), LED20.1 (VDD), LED21.1 (VDD), LED22.1 (VDD), LED23.1 (VDD), LED24.1 (VDD), LED25.1 (VDD), LED26.1 (VDD), LED27.1 (VDD), LED28.1 (VDD), LED29.1 (VDD), LED30.1 (VDD), LED31.1 (VDD), LED32.1 (VDD), LED33.1 (VDD), LED34.1 (VDD), LED35.1 (VDD), TP1.1, U2.39 (VSYS), U3.5 (VCC), begin1.1, end1.1
Col 0: S1.1, S2.1, S3.1, S4.1, U2.29 (GPIO22)
Col 1: S5.1, S6.1, S7.1, U2.26 (GPIO20)
Col 2: S8.1, S9.1, S10.1, S11.1, U2.17 (GPIO13)
Col 3: S12.1, S13.1, S14.1, S15.1, S16.1, U2.12 (GPIO9)
Col 4: S17.1, S18.1, S19.1, S20.1, S21.1, S22.1, U2.15 (GPIO11)
Col 5: S23.1, S24.1, S25.1, S26.1, S27.1, U2.4 (GPIO2)
Col 6: S28.1, S29.1, S30.1, S31.1, S32.1, U2.5 (GPIO3)
Col 7: S33.1, S34.1, U2.1 (GPIO0)
Col 8: S35.1, U2.2 (GPIO1)
Data+: J4.2, U2.44 (data+)
Data-: J4.1, U2.45 (data-)
GND: J1.1, J3.4, JP1.2 (B), LED1.3 (VSS), LED2.3 (VSS), LED3.3 (VSS), LED4.3 (VSS), LED5.3 (VSS), LED6.3 (VSS), LED7.3 (VSS), LED8.3 (VSS), LED9.3 (VSS), LED10.3 (VSS), LED11.3 (VSS), LED12.3 (VSS), LED13.3 (VSS), LED14.3 (VSS), LED15.3 (VSS), LED16.3 (VSS), LED17.3 (VSS), LED18.3 (VSS), LED19.3 (VSS), LED20.3 (VSS), LED21.3 (VSS), LED22.3 (VSS), LED23.3 (VSS), LED24.3 (VSS), LED25.3 (VSS), LED26.3 (VSS), LED27.3 (VSS), LED28.3 (VSS), LED29.3 (VSS), LED30.3 (VSS), LED31.3 (VSS), LED32.3 (VSS), LED33.3 (VSS), LED34.3 (VSS), LED35.3 (VSS), TP2.1, U2.8 (GND), U2.13 (GND), U2.18 (GND), U2.23 (GND), U2.28 (GND), U2.42 (GND), U3.3 (GND), begin1.2, end1.2
LED 3.3V: JP4.2 (B), TP3.1, U2.14 (GPIO10), U3.2
LED 5V: JP3.1 (A), JP4.1 (A), U3.4
unnamed: D1.2 (A), S1.2
unnamed: D2.2 (A), S2.2
unnamed: D3.2 (A), S3.2
unnamed: D4.2 (A), S4.2
unnamed: D5.2 (A), S5.2
unnamed: D6.2 (A), S6.2
unnamed: D7.2 (A), S7.2
unnamed: D8.2 (A), S8.2
unnamed: D9.2 (A), S9.2
unnamed: D10.2 (A), S10.2
unnamed: D11.2 (A), S11.2
unnamed: D12.2 (A), S12.2
unnamed: D13.2 (A), S13.2
unnamed: D14.2 (A), S14.2
unnamed: D15.2 (A), S15.2
unnamed: D16.2 (A), S16.2
unnamed: D17.2 (A), S17.2
unnamed: D18.2 (A), S18.2
unnamed: D19.2 (A), S19.2
unnamed: D20.2 (A), S20.2
unnamed: D21.2 (A), S21.2
unnamed: D22.2 (A), S22.2
unnamed: D23.2 (A), S23.2
unnamed: D24.2 (A), S24.2
unnamed: D25.2 (A), S25.2
unnamed: D26.2 (A), S26.2
unnamed: D27.2 (A), S27.2
unnamed: D28.2 (A), S28.2
unnamed: D29.2 (A), S29.2
unnamed: D30.2 (A), S30.2
unnamed: D31.2 (A), S31.2
unnamed: D32.2 (A), S32.2
unnamed: D33.2 (A), S33.2
unnamed: D34.2 (A), S34.2
unnamed: D35.2 (A), S35.2
unnamed: JP3.2 (B), LED20.4 (DIN)
unnamed: LED1.4 (DIN), LED6.2 (DOUT)
unnamed: LED2.4 (DIN), LED3.2 (DOUT)
unnamed: LED2.2 (DOUT), LED8.4 (DIN)
unnamed: LED3.4 (DIN), LED9.2 (DOUT)
unnamed: LED4.4 (DIN), LED7.2 (DOUT)
unnamed: LED4.2 (DOUT), LED5.4 (DIN)
unnamed: LED10.4 (DIN), LED15.2 (DOUT)
unnamed: LED6.4 (DIN), LED10.2 (DOUT)
unnamed: LED5.2 (DOUT), LED11.4 (DIN)
unnamed: LED11.2 (DOUT), LED16.4 (DIN)
unnamed: LED8.2 (DOUT), LED12.4 (DIN)
unnamed: LED12.2 (DOUT), LED17.4 (DIN)
unnamed: LED13.4 (DIN), LED21.2 (DOUT)
unnamed: LED7.4 (DIN), LED13.2 (DOUT)
unnamed: LED14.4 (DIN), LED18.2 (DOUT)
unnamed: LED9.4 (DIN), LED14.2 (DOUT)
unnamed: LED15.4 (DIN), LED19.2 (DOUT)
unnamed: LED16.2 (DOUT), LED22.4 (DIN)
unnamed: LED17.2 (DOUT), LED23.4 (DIN)
unnamed: LED18.4 (DIN), LED24.2 (DOUT)
unnamed: LED19.4 (DIN), LED25.2 (DOUT)
unnamed: LED20.2 (DOUT), LED29.4 (DIN)
unnamed: LED21.4 (DIN), LED26.2 (DOUT)
unnamed: LED22.2 (DOUT), LED27.4 (DIN)
unnamed: LED23.2 (DOUT), LED28.4 (DIN)
unnamed: LED24.4 (DIN), LED30.2 (DOUT)
unnamed: LED25.4 (DIN), LED31.2 (DOUT)
unnamed: LED26.4 (DIN), LED33.2 (DOUT)
unnamed: LED27.2 (DOUT), LED32.4 (DIN)
unnamed: LED28.2 (DOUT), LED31.4 (DIN)
unnamed: LED29.2 (DOUT), LED35.4 (DIN)
unnamed: LED30.4 (DIN), LED34.2 (DOUT)
unnamed: LED32.2 (DOUT), LED34.4 (DIN)
unnamed: LED33.4 (DIN), LED35.2 (DOUT)
RX: J1.3, U2.21 (GPIO16)
Row 0: D1.1 (K), D6.1 (K), D10.1 (K), D15.1 (K), D19.1 (K), D25.1 (K), D31.1 (K), U2.25 (GPIO19)
Row 1: D2.1 (K), D8.1 (K), D12.1 (K), D17.1 (K), D23.1 (K), D28.1 (K), U2.27 (GPIO21)
Row 2: D3.1 (K), D9.1 (K), D14.1 (K), D18.1 (K), D24.1 (K), D30.1 (K), U2.24 (GPIO18)
Row 3: D5.1 (K), D11.1 (K), D16.1 (K), D22.1 (K), D27.1 (K), D32.1 (K), D34.1 (K), U2.16 (GPIO12)
Row 4: D4.1 (K), D7.1 (K), D13.1 (K), D21.1 (K), D26.1 (K), D33.1 (K), D35.1 (K), U2.6 (GPIO4)
Row 5: D20.1 (K), D29.1 (K), U2.11 (GPIO8)
SCL: J3.2, U2.10 (GPIO7)
SDA: J3.1, U2.9 (GPIO6)
SPLIT_HAND_PIN: JP1.1 (A), JP2.1 (A), U2.31 (GPIO26_ADC0)
TX: J1.2, U2.22 (GPIO17)

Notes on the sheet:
Switch matrix
USB connector
for EE_HANDS
SERIAL connector (TRRS)
Mounting Hole PCB - case
LED matrix
Mounting Hole plate - cover
Mounting Hole PCB - cover (pcb support)
Microcontroller
OLED display
TP3: D+
Not enought for the VCC and GND connector
TP2: D-

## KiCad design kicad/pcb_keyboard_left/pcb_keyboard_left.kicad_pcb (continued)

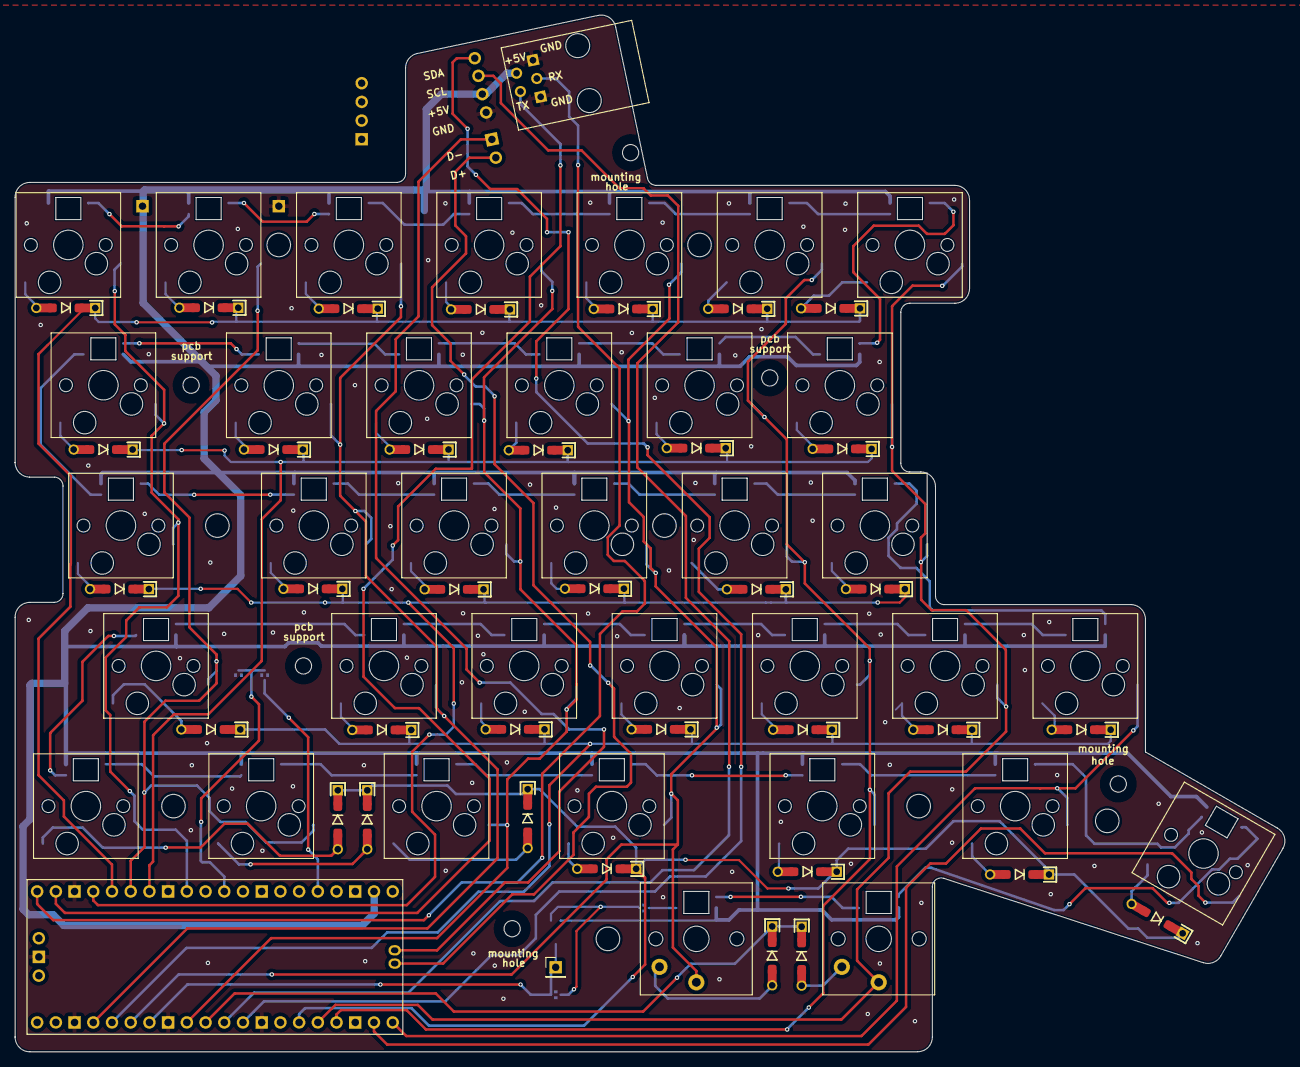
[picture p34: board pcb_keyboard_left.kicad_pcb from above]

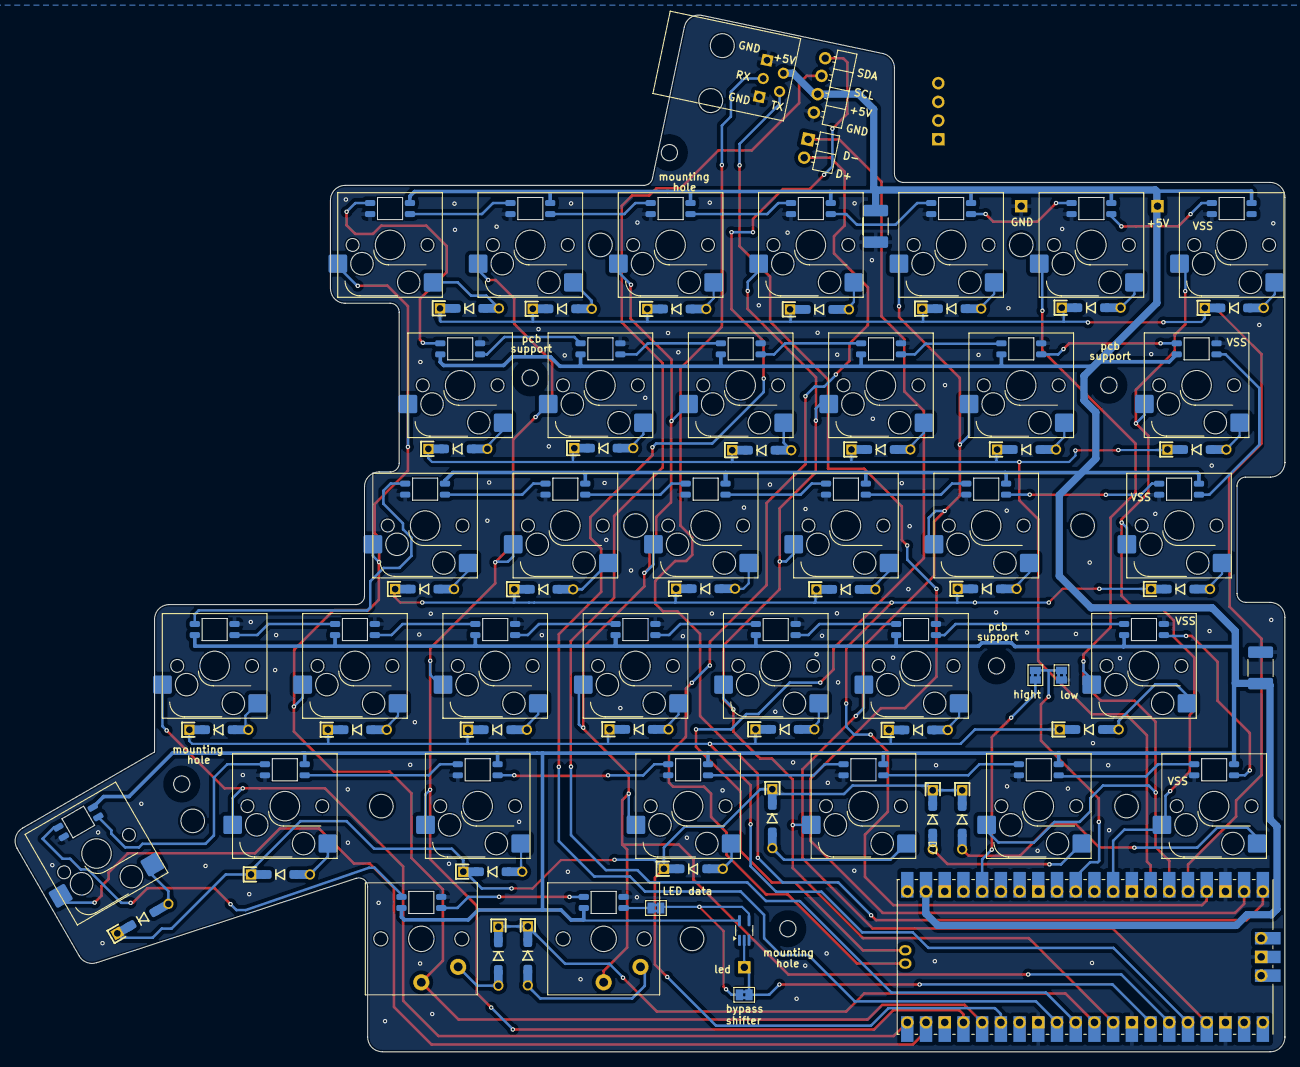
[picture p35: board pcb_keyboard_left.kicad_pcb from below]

Board: 2 copper layers, 172.4 x 140.7 mm, 134 parts (79 on the bottom side), 97 nets.

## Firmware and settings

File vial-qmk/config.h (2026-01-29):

#pragma once

#define EE_HANDS                 // Sets the keyboard’s handedness using EEPROM
#define SERIAL_USART_FULL_DUPLEX
#define SERIAL_USART_TX_PIN GP17
#define SERIAL_USART_RX_PIN GP16
#define SERIAL_USART_PIN_SWAP  // Swap TX and RX pins if keyboard is master halve. (Only available on some MCUs)
// #define SPLIT_MAX_CONNECTION_ERRORS 10 //per usare il master senza lo slave
#define SPLIT_USB_DETECT
#define SPLIT_TRANSPORT_MIRROR
#define SPLIT_RGB_MATRIX_ENABLE
#define SPLIT_LAYER_STATE_ENABLE
#define SPLIT_MODS_ENABLE
#define SPLIT_LED_STATE_ENABLE
#define SPLIT_TRANSPORT_SYNC_ENABLE

// oled
#define I2C_DRIVER I2CD1
#define I2C1_SDA_PIN GP6
#define I2C1_SCL_PIN GP7
#ifdef OLED_ENABLE
  #define OLED_DISPLAY_128X32
  #define OLED_TIMEOUT 5000 //5 sec
  #define OLED_BRIGHTNESS 170
#endif

// encoders
#define NUM_ENCODERS 1
#define ENCODERS_PAD { GP14, GP15 } //vial requirements (but It sees that work with the next definitions too)
#define ENCODER_RESOLUTION 4


// rgb
#ifdef RGB_MATRIX_ENABLE
  #define RGB_MATRIX_VAL_STEP 3
  #define RGB_MATRIX_MAXIMUM_BRIGHTNESS 220
  #define RGB_MATRIX_KEYPRESSES // reacts to keypresses
  #define RGB_MATRIX_FRAMEBUFFER_EFFECTS
  #define RGB_MATRIX_SLEEP // turn off effects when suspended
  #define RGB_MATRIX_TIMEOUT 180000 // number of milliseconds to wait until rgb automatically turns off (180000 are 3 min)
#endif

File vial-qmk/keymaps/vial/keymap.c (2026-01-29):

#include QMK_KEYBOARD_H
#include "quantum.h"
#include "oled_images.h"
#include "oled_driver.h" // assicurati che sia incluso il driver corretto

enum custom_keycodes {
    KC_LSTRT = QK_KB_0, // we use QK_KB_0 instead of SAFE_RANGE, to see the right name in VIAL interface (KC_LSTRT is start of line)
    KC_LEND, // go to: end of line
    KC_DLINE, // del word
    BRIGHTNESS_CICLE,
    RGB_COL_TOGGLE,
    KC_E_GRAVE, // write é
    MOVE_RIGHT_MACOS,
    MOVE_LEFT_MACOS,
    KC_MARKDOWN_CODE_BLOCK
};

/*                                                MY TARGET

    GPIO:  0     1    2   3     4    5    6                       7   8     9   10   11  12 (13)  14
         ┌────┬────┬────┬────┬────┬────┬────┐                  ┌────┬────┬────┬────┬────┬────┬─────────┐
    15   │Esc │ 1  │  2 │  3 │  4 │  5 │  6 │                  │ 7  │  8 │  9 │  0 │  - │  + │  Backsp │
         ├────┴──┬─┴──┬─┴──┬─┴──┬─┴──┬─┴──┬─┴──┐               └──┬─┴──┬─┴──┬─┴──┬─┴──┬─┴──┬─┴──┬──────┤
    16   │ Tab   │ Q  │  W │  E │  R │  T │  Y │                  │ U  │  I │ O  │ P  │ [  │  ] │  \|  │
         ├───────┴┬───┴┬───┴┬───┴┬───┴┬───┴┬───┘              ┌───┴┬───┴┬───┴┬───┴┬───┴┬───┴┬───┴──────│
    17   │ Caps   │ A  │ S  │ D  │ F  │ G  │                  │ H  │ J  │  K │  L │ ;  │ '  │  Enter   │
         ├──────┬─┴──┬─┴──┬─┴──┬─┴──┬─┴──┬─┴──┬────┐          └──┬─┴──┬─┴──┬─┴──┬─┴──┬─┴──┬─┴──────────┤
    18   │Shf   │ <  │  Z │  X │  C │  V │  B │ F1 │             │  N │  M │ ,  │  . │  ? │    Shf     │
         ├─────┬┴────┼────┴┬───┴─┬──┴────┴──┬─┴──┬─┴──┐        ┌─┴────┴┬───┴─┬──┴────┼────┴┬─────┬─────┤
    19   │ FN  │ Ctrl│ Win │ Alt │  Space   │ ent│bspc│        │ Space │ FN  │  Alt  │ Gui │  <  │  >  │
         └─────┴─────┴─────┴───┬─┴─────┬────┼────┴────┘        ├─────┬─┴─────┴┬──────┴─────┴─────┴─────┘
    20                         │   F4  │ F5 │                  │  F6 │   F7   │
                               └───────┴────┘                  └─────┴────────┘
*/ 
const uint16_t PROGMEM keymaps[][MATRIX_ROWS][MATRIX_COLS] = {
    [0] = LAYOUT(
      KC_ESC, KC_1, KC_2, KC_3, KC_4, KC_5, KC_6,                                               KC_7, KC_8, KC_9, KC_0, KC_MINS, KC_EQL, KC_BSPC, 
      KC_TAB, KC_Q, KC_W, KC_E, KC_R, KC_T,                                                 KC_Y, KC_U, KC_I, KC_O, KC_P, KC_LBRC, KC_RBRC, KC_BSLS,          KC_MUTE,
      KC_CAPS, KC_A, KC_S, KC_D, KC_F, KC_G,                                                 KC_H, KC_J, KC_K, KC_L, KC_SCLN, KC_QUOT, KC_ENT, 
      KC_LSFT, KC_Z, KC_X, KC_C, KC_V, KC_B, KC_DEL,                                         KC_N, KC_M, KC_COMM, KC_DOT, KC_SLSH, KC_RSFT, 
      MO(1), KC_LCTL, KC_LGUI, KC_LALT, KC_SPC, KC_ENT, KC_BSPC,                            KC_SPC, KC_RCTL, KC_RGUI, _______, KC_RCTL, KC_RIGHT,
                                MO(2), MO(1),                                              MO(1), MO(2)
    ),

    [1] = LAYOUT(
      KC_GRAVE, KC_F1, KC_F2, KC_F3, KC_F4, KC_F5, KC_F6,                                          KC_F7, KC_F8, KC_F9, KC_F10, KC_F11, KC_F12, KC_DEL, 
      _______, _______, _______, KC_E_GRAVE, _______, _______,                                    KC_VOLD, KC_VOLU, KC_UP, _______, _______, _______, _______, _______,         _______,
      _______, _______, _______, KC_BSPC, _______, _______,                                           _______, KC_LEFT, KC_DOWN, KC_RIGHT, _______, _______, _______, 
      _______, _______, _______, _______, _______, _______, _______,                                     MOVE_LEFT_MACOS, MOVE_RIGHT_MACOS, _______, _______, _______, _______, 
      KC_MARKDOWN_CODE_BLOCK, RGB_TOG, _______, _______, _______, _______, _______,                    RGB_TOG, BRIGHTNESS_CICLE, RGB_COL_TOGGLE, _______, MOVE_LEFT_MACOS, MOVE_RIGHT_MACOS,
                                _______, _______,                                                    _______, _______
    ),

    [2] = LAYOUT(
QK_MAGIC_SWAP_LCTL_LGUI, QK_MAGIC_UNSWAP_LCTL_LGUI, KC_F2, KC_F3, KC_F4, KC_F5, QK_BOOTLOADER,                            QK_BOOTLOADER, KC_F8, KC_F9, KC_F10, KC_F11, KC_F12, KC_DLINE, 
      _______, _______, KC_UP, _______, _______, _______,                                    _______, _______, KC_MS_U, _______, _______, _______, _______, _______,         _______,
      _______, KC_LEFT, KC_DOWN, KC_RIGHT, _______, _______,                                    KC_BTN1, KC_MS_L, KC_MS_D, KC_MS_R, KC_BTN2, _______, _______, 
      _______, _______, _______, _______, _______, _______, _______,                                KC_WH_U, _______, _______, _______, _______, _______, 
      _______, _______, _______, _______, _______, _______, _______,                        KC_WH_U, _______, _______, _______, _______, _______,
                                       _______, _______,                                    _______, _______
    ),
};

/* ENCODER */
#if defined(ENCODER_MAP_ENABLE)
const uint16_t PROGMEM encoder_map[][NUM_ENCODERS][2] = {
    [0] =   { ENCODER_CCW_CW(KC_VOLD, KC_VOLU),   },
    [1] =   { ENCODER_CCW_CW(KC_BRID, KC_BRIU),   },
    [2] =   { ENCODER_CCW_CW(KC_TRNS, KC_TRNS),   },
};
#endif



void matrix_scan_user(void) {
    static uint32_t last_toggle = 0;
    static bool led_on = false;

    if (timer_elapsed32(last_toggle) > 500) {
        last_toggle = timer_read32();
        setPinOutput(GP25);
        if (led_on) {
            writePinLow(GP25);
        } else {
            writePinHigh(GP25);
        }
        led_on = !led_on;   
    }    
}


static uint8_t brightness_level = 0;  // 0 = low, 1 = medium, 2 = hight
// --- OS image switch overlay ---
static uint32_t os_img_timer = 0;
static uint8_t os_img_to_show = 0;
static uint8_t color_index = 0;
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

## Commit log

2025-06-10 level shifter added also for sx part
    [pcb_keyboard_sx.kicad_pcb, pcb_keyboard_sx.kicad_sch]
2025-06-10 added d+ and d- bus
    [pcb_keyboard_dx.kicad_pcb, pcb_keyboard_dx.kicad_sch, pcb_keyboard_sx.kicad_pcb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]
2025-06-25 stessi GPIO per dx e sx
    [pcb_keyboard_dx.kicad_pcb, pcb_keyboard_dx.kicad_sch, pcb_keyboard_sx.kicad_pcb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]
2025-06-25 gitignore aggiornato per kicad projects
2025-06-25 Rimuovi file ignorati dal tracking
    [BOM-complete_plate_6.csv, BOM-pcb_keyboard_dx.csv, BOM-pcb_keyboard_dx_no_smd.csv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]
2025-08-09 tastiera con rj11 mandata in stampa
    [OLED_128x32.step, RJ11_CONNECTOR.step, Raspberry_Pi_Pico.step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]
2026-01-29 create new folder for kicad, updated 3d_models, update readme
    [3-key_keypad.stl, OLED_128x32.step, RJ11_CONNECTOR.step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]
2026-01-29 added key matrix wiring chapter in readme
2026-01-29 change names of kicad files
    [pcb_keyboard_dx_rj11-CuBottom.gbr, pcb_keyboard_dx_rj11-CuTop.gbr, pcb_keyboard_dx_rj11-EdgeCuts.gbr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]
2026-01-29 added 3d print info and repository structure info
